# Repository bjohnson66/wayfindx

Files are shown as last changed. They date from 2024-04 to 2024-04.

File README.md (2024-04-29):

# WayFindX

WayFindX is a handheld GPS receiver project developed by Bradley Johnson and Abele Atresso. The project aims to create a portable navigation device that enhances outdoor navigation capabilities for users such as hikers, adventurers, and outdoor enthusiasts. WayFindX provides essential features including position and velocity tracking, storage of multiple locations, and distance calculation to selected stored positions.

# Youtube Promo

IWayFindX Promo Video (https://www.youtube.com/watch?v=03FtzsMHSRk)

## Key Features

- Display of user position and velocity information
- Storage of multiple locations for navigation
- Calculation of distance to selected stored positions
- Intuitive user interface with control buttons and LCD display

## Hardware Components

The project utilizes the following hardware components:

- Arduino microcontroller (ATMega328p)
- HD44780 Controlled 20x4 LCD for display
- Four buttons for user input
- NEO-6M GPS module for positioning
- Power Switch and 9V battery for power management
- Additional components for connectivity
- Custom-designed 3D printed case for enclosure

## Software Interface

WayFindX provides a user-friendly interface with control buttons for navigation and interaction. The software is designed to display essential information such as current position, stored locations, and operational modes on the LCD display. Users can cycle through saved positions, select operations, and execute actions with ease.

## Challenges Faced

The project encountered various challenges including serial communication, interfacing with new ICs, soldering, and enclosure design. Overcoming these challenges required careful planning, experimentation, and troubleshooting.

For detailed documentation and code implementation, refer to the project source code and comments.

See /docs for relevant hardware, software, and misc documentation.

[Doxygen HTML Documentation](https://raw.githubusercontent.com/bjohnson66/wayfindx/main/docs/Doxygen/html/index.html)

[Doxygen PDF Documentatoin](https://github.com/bjohnson66/wayfindx/blob/88b1bcc49ac1252769d0535202fbb5b85fcedd5b/docs/Doxygen/doxygen_latex_pdf_out.pdf)

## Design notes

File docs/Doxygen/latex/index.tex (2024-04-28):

\chapter{Way\+FindX}
\hypertarget{index}{}\label{index}\index{WayFindX@{WayFindX}}
Synopsis of the Way\+FindX Embedded Systems Project.

Synopsis of the Way\+FindX Embedded Systems Project.   

Way\+FindX is a handheld GPS receiver project developed by Avengers Assembly, consisting of Bradley Johnson and Abele Atresso. The project aims to create a portable navigation device that enhances outdoor navigation capabilities for users such as hikers, adventurers, and outdoor enthusiasts. Way\+FindX provides essential features including position and velocity tracking, storage of multiple locations, and distance calculation to selected stored positions.\hypertarget{index_features}{}\doxysection{\texorpdfstring{Key Features}{Key Features}}\label{index_features}

\begin{DoxyItemize}
\item Display of user position and velocity information
\item Storage of multiple locations for navigation
\item Calculation of distance to selected stored positions
\item Intuitive user interface with control buttons and LCD display
\end{DoxyItemize}\hypertarget{index_hardware}{}\doxysection{\texorpdfstring{Hardware Components}{Hardware Components}}\label{index_hardware}
The project utilizes the following hardware components\+:
\begin{DoxyItemize}
\item Arduino microcontroller (ATMega328p)
\item HD44780 Controlled 20x4 LCD for display
\item Control Stick for user input
\item NEO-\/6M GPS module for positioning
\item Power Switch and 9V battery for power management
\item Additional components for connectivity
\item Custom-\/designed 3D printed case for enclosure
\end{DoxyItemize}\hypertarget{index_software}{}\doxysection{\texorpdfstring{Software Interface}{Software Interface}}\label{index_software}
Way\+FindX provides a user-\/friendly interface with control buttons for navigation and interaction. The software is designed to display essential information such as current position, stored locations, and operational modes on the LCD display. Users can cycle through saved positions, select operations, and execute actions with ease.\hypertarget{index_challenges}{}\doxysection{\texorpdfstring{Challenges Faced}{Challenges Faced}}\label{index_challenges}
The project encountered various challenges including serial communication, interfacing with new ICs, soldering, and enclosure design. Overcoming these challenges required careful planning, experimentation, and troubleshooting.

For detailed documentation and code implementation, refer to the project source code and comments.\textbackslash{} \begin{DoxyVersion}{Version}
1.\+0 
\end{DoxyVersion}
\begin{DoxyCopyright}{Copyright}
(C) 2024 Bradley Johnson and Abele Atresso 
\end{DoxyCopyright}

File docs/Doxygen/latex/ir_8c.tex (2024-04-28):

\doxysection{G\+:/\+Project\+\_\+\+Files/\+Way\+Find\+X/wfx\+\_\+sw/wfx\+\_\+sw/ir/ir.c File Reference}
\hypertarget{ir_8c}{}\label{ir_8c}\index{G:/Project\_Files/WayFindX/wfx\_sw/wfx\_sw/ir/ir.c@{G:/Project\_Files/WayFindX/wfx\_sw/wfx\_sw/ir/ir.c}}
{\ttfamily \#include "{}ir.\+h"{}}\newline
{\ttfamily \#include $<$avr/interrupt.\+h$>$}\newline
{\ttfamily \#include "{}../ut/utilities.\+h"{}}\newline
\doxysubsubsection*{Functions}
\begin{DoxyCompactItemize}
\item 
\mbox{\hyperlink{ir_8c_add2d7cdddfb682dcc0391e60cf42c7d6}{ISR}} (TIMER0\+\_\+\+OVF\+\_\+vect)
\item 
\mbox{\hyperlink{ir_8c_a7cfcbe42bd266750aeb6e5d71e5ea479}{ISR}} (TIMER2\+\_\+\+OVF\+\_\+vect)
\item 
void \mbox{\hyperlink{ir_8c_a398213820d1862c262f45bb51a4bb934}{ir\+\_\+init}} ()
\begin{DoxyCompactList}\small\item\em Initializes interrupt system functionality. \end{DoxyCompactList}\end{DoxyCompactItemize}
\doxysubsubsection*{Variables}
\begin{DoxyCompactItemize}
\item 
\mbox{\hyperlink{ut__types_8h_a1f1825b69244eb3ad2c7165ddc99c956}{uint16\+\_\+t}} \mbox{\hyperlink{ir_8c_a420cef67ebc0cf3d472f957806f1b8b4}{ir\+\_\+sec\+\_\+counter}} = 0
\item 
\mbox{\hyperlink{ut__types_8h_a5338510a6d3a27844de9a766a4303d46}{boolean\+\_\+t}} \mbox{\hyperlink{ir_8c_a3869ada31829485498d4bdbf1d4cc6e9}{ir\+\_\+trigger\+\_\+1hz\+\_\+flag\+\_\+g}} = \mbox{\hyperlink{ut__types_8h_a65e9886d74aaee76545e83dd09011727}{false}}
\end{DoxyCompactItemize}

\doxysubsection{Function Documentation}
\Hypertarget{ir_8c_a398213820d1862c262f45bb51a4bb934}\label{ir_8c_a398213820d1862c262f45bb51a4bb934} 
\index{ir.c@{ir.c}!ir\_init@{ir\_init}}
\index{ir\_init@{ir\_init}!ir.c@{ir.c}}
\doxysubsubsection{\texorpdfstring{ir\_init()}{ir\_init()}}
{\footnotesize\ttfamily void ir\+\_\+init (\begin{DoxyParamCaption}{ }\end{DoxyParamCaption})}

Initializes interrupt system functionality. 

This function configures Timer2 for time management and Timer 0 for background button polling. 

Definition at line \mbox{\hyperlink{ir_8c_source_l00038}{38}} of file \mbox{\hyperlink{ir_8c_source}{ir.\+c}}.

\Hypertarget{ir_8c_add2d7cdddfb682dcc0391e60cf42c7d6}\label{ir_8c_add2d7cdddfb682dcc0391e60cf42c7d6} 
\index{ir.c@{ir.c}!ISR@{ISR}}
\index{ISR@{ISR}!ir.c@{ir.c}}
\doxysubsubsection{\texorpdfstring{ISR()}{ISR()}\hspace{0.1cm}{\footnotesize\ttfamily [1/2]}}
{\footnotesize\ttfamily ISR (\begin{DoxyParamCaption}\item[{TIMER0\+\_\+\+OVF\+\_\+vect}]{ }\end{DoxyParamCaption})}

Definition at line \mbox{\hyperlink{ir_8c_source_l00016}{16}} of file \mbox{\hyperlink{ir_8c_source}{ir.\+c}}.

\Hypertarget{ir_8c_a7cfcbe42bd266750aeb6e5d71e5ea479}\label{ir_8c_a7cfcbe42bd266750aeb6e5d71e5ea479} 
\index{ir.c@{ir.c}!ISR@{ISR}}
\index{ISR@{ISR}!ir.c@{ir.c}}
\doxysubsubsection{\texorpdfstring{ISR()}{ISR()}\hspace{0.1cm}{\footnotesize\ttfamily [2/2]}}
{\footnotesize\ttfamily ISR (\begin{DoxyParamCaption}\item[{TIMER2\+\_\+\+OVF\+\_\+vect}]{ }\end{DoxyParamCaption})}

Definition at line \mbox{\hyperlink{ir_8c_source_l00022}{22}} of file \mbox{\hyperlink{ir_8c_source}{ir.\+c}}.

\doxysubsection{Variable Documentation}
\Hypertarget{ir_8c_a420cef67ebc0cf3d472f957806f1b8b4}\label{ir_8c_a420cef67ebc0cf3d472f957806f1b8b4} 
\index{ir.c@{ir.c}!ir\_sec\_counter@{ir\_sec\_counter}}
\index{ir\_sec\_counter@{ir\_sec\_counter}!ir.c@{ir.c}}
\doxysubsubsection{\texorpdfstring{ir\_sec\_counter}{ir\_sec\_counter}}
{\footnotesize\ttfamily \mbox{\hyperlink{ut__types_8h_a1f1825b69244eb3ad2c7165ddc99c956}{uint16\+\_\+t}} ir\+\_\+sec\+\_\+counter = 0}

Seconds counter for indicating TTFF 

Definition at line \mbox{\hyperlink{ir_8c_source_l00006}{6}} of file \mbox{\hyperlink{ir_8c_source}{ir.\+c}}.

\Hypertarget{ir_8c_a3869ada31829485498d4bdbf1d4cc6e9}\label{ir_8c_a3869ada31829485498d4bdbf1d4cc6e9} 
\index{ir.c@{ir.c}!ir\_trigger\_1hz\_flag\_g@{ir\_trigger\_1hz\_flag\_g}}
\index{ir\_trigger\_1hz\_flag\_g@{ir\_trigger\_1hz\_flag\_g}!ir.c@{ir.c}}
\doxysubsubsection{\texorpdfstring{ir\_trigger\_1hz\_flag\_g}{ir\_trigger\_1hz\_flag\_g}}
{\footnotesize\ttfamily \mbox{\hyperlink{ut__types_8h_a5338510a6d3a27844de9a766a4303d46}{boolean\+\_\+t}} ir\+\_\+trigger\+\_\+1hz\+\_\+flag\+\_\+g = \mbox{\hyperlink{ut__types_8h_a65e9886d74aaee76545e83dd09011727}{false}}}

Global flag indicating 1Hz trigger 

Definition at line \mbox{\hyperlink{ir_8c_source_l00007}{7}} of file \mbox{\hyperlink{ir_8c_source}{ir.\+c}}.

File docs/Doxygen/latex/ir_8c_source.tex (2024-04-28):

\doxysection{ir.\+c}
\hypertarget{ir_8c_source}{}\label{ir_8c_source}\index{G:/Project\_Files/WayFindX/wfx\_sw/wfx\_sw/ir/ir.c@{G:/Project\_Files/WayFindX/wfx\_sw/wfx\_sw/ir/ir.c}}
\mbox{\hyperlink{ir_8c}{Go to the documentation of this file.}}
\begin{DoxyCode}{0}
\DoxyCodeLine{\Hypertarget{ir_8c_source_l00001}00001\ \textcolor{preprocessor}{\#include\ "{}\mbox{\hyperlink{ir_8h}{ir.h}}"{}}}
\DoxyCodeLine{\Hypertarget{ir_8c_source_l00002}00002\ \textcolor{preprocessor}{\#include\ <avr/interrupt.h>}}
\DoxyCodeLine{\Hypertarget{ir_8c_source_l00003}00003\ \textcolor{preprocessor}{\#include\ "{}\mbox{\hyperlink{utilities_8h}{../ut/utilities.h}}"{}}}
\DoxyCodeLine{\Hypertarget{ir_8c_source_l00004}00004\ }
\DoxyCodeLine{\Hypertarget{ir_8c_source_l00005}00005\ \textcolor{comment}{//global}}
\DoxyCodeLine{\Hypertarget{ir_8c_source_l00006}\mbox{\hyperlink{ir_8c_a420cef67ebc0cf3d472f957806f1b8b4}{00006}}\ \mbox{\hyperlink{ut__types_8h_a1f1825b69244eb3ad2c7165ddc99c956}{uint16\_t}}\ \mbox{\hyperlink{ir_8c_a420cef67ebc0cf3d472f957806f1b8b4}{ir\_sec\_counter}}\ =\ 0;\ }
\DoxyCodeLine{\Hypertarget{ir_8c_source_l00007}\mbox{\hyperlink{ir_8c_a3869ada31829485498d4bdbf1d4cc6e9}{00007}}\ \mbox{\hyperlink{ut__types_8h_a5338510a6d3a27844de9a766a4303d46}{boolean\_t}}\ \mbox{\hyperlink{ir_8c_a3869ada31829485498d4bdbf1d4cc6e9}{ir\_trigger\_1hz\_flag\_g}}\ =\ \textcolor{keyword}{false};\ }
\DoxyCodeLine{\Hypertarget{ir_8c_source_l00011}00011\ \textcolor{comment}{//local\ static}}
\DoxyCodeLine{\Hypertarget{ir_8c_source_l00012}00012\ \textcolor{keyword}{static}\ \mbox{\hyperlink{ut__types_8h_aba7bc1797add20fe3efdf37ced1182c5}{uint8\_t}}\ timer2\_overflow\_counter;}
\DoxyCodeLine{\Hypertarget{ir_8c_source_l00013}00013\ }
\DoxyCodeLine{\Hypertarget{ir_8c_source_l00014}00014\ }
\DoxyCodeLine{\Hypertarget{ir_8c_source_l00015}00015\ \textcolor{comment}{//\ Interrupt\ Service\ Routine\ for\ Timer0\ overflow:\ Poll\ all\ four\ buttons\ in\ background\ set\ state\ if\ we\ have\ polled\ enough\ times}}
\DoxyCodeLine{\Hypertarget{ir_8c_source_l00016}\mbox{\hyperlink{ir_8c_add2d7cdddfb682dcc0391e60cf42c7d6}{00016}}\ \mbox{\hyperlink{ir_8c_add2d7cdddfb682dcc0391e60cf42c7d6}{ISR}}(TIMER0\_OVF\_vect)\ \{}
\DoxyCodeLine{\Hypertarget{ir_8c_source_l00017}00017\ \ \ \ \ \mbox{\hyperlink{utilities_8c_a88ffabf71aed5f9ff12e47960d74ad3a}{ut\_poll\_btns}}();}
\DoxyCodeLine{\Hypertarget{ir_8c_source_l00018}00018\ \ \ \ \ TCNT0\ =\ 0;}
\DoxyCodeLine{\Hypertarget{ir_8c_source_l00019}00019\ \}}
\DoxyCodeLine{\Hypertarget{ir_8c_source_l00020}00020\ }
\DoxyCodeLine{\Hypertarget{ir_8c_source_l00021}00021\ \textcolor{comment}{//\ Interrupt\ Service\ Routine\ for\ Timer2\ overflow:\ Used\ to\ trip\ trigger\ flag\ at\ 1Hz}}
\DoxyCodeLine{\Hypertarget{ir_8c_source_l00022}\mbox{\hyperlink{ir_8c_a7cfcbe42bd266750aeb6e5d71e5ea479}{00022}}\ \mbox{\hyperlink{ir_8c_add2d7cdddfb682dcc0391e60cf42c7d6}{ISR}}(TIMER2\_OVF\_vect)\ \{}
\DoxyCodeLine{\Hypertarget{ir_8c_source_l00023}00023\ \ \ \ \ timer2\_overflow\_counter++;}
\DoxyCodeLine{\Hypertarget{ir_8c_source_l00024}00024\ \ \ \ \ \textcolor{keywordflow}{if}\ (timer2\_overflow\_counter\ >=\ 15)\{}
\DoxyCodeLine{\Hypertarget{ir_8c_source_l00025}00025\ \ \ \ \ \ \ \ \ timer2\_overflow\_counter\ =\ 0;}
\DoxyCodeLine{\Hypertarget{ir_8c_source_l00026}00026\ \ \ \ \ \ \ \ \ \mbox{\hyperlink{ir_8c_a420cef67ebc0cf3d472f957806f1b8b4}{ir\_sec\_counter}}++;}
\DoxyCodeLine{\Hypertarget{ir_8c_source_l00027}00027\ \ \ \ \ \ \ \ \ \textcolor{keywordflow}{if}\ (!\mbox{\hyperlink{ir_8c_a3869ada31829485498d4bdbf1d4cc6e9}{ir\_trigger\_1hz\_flag\_g}})\{}
\DoxyCodeLine{\Hypertarget{ir_8c_source_l00028}00028\ \ \ \ \ \ \ \ \ \ \ \ \ \mbox{\hyperlink{ir_8c_a3869ada31829485498d4bdbf1d4cc6e9}{ir\_trigger\_1hz\_flag\_g}}\ =\ \textcolor{keyword}{true};}
\DoxyCodeLine{\Hypertarget{ir_8c_source_l00029}00029\ \ \ \ \ \ \ \ \ \}}
\DoxyCodeLine{\Hypertarget{ir_8c_source_l00030}00030\ \ \ \ \ \}}
\DoxyCodeLine{\Hypertarget{ir_8c_source_l00031}00031\ \}}
\DoxyCodeLine{\Hypertarget{ir_8c_source_l00032}00032\ }
\DoxyCodeLine{\Hypertarget{ir_8c_source_l00038}\mbox{\hyperlink{ir_8c_a398213820d1862c262f45bb51a4bb934}{00038}}\ \textcolor{keywordtype}{void}\ \mbox{\hyperlink{ir_8c_a398213820d1862c262f45bb51a4bb934}{ir\_init}}()}
\DoxyCodeLine{\Hypertarget{ir_8c_source_l00039}00039\ \{}
\DoxyCodeLine{\Hypertarget{ir_8c_source_l00040}00040\ \ \ \ \ cli();}
\DoxyCodeLine{\Hypertarget{ir_8c_source_l00041}00041\ \ \ \ \ \textcolor{comment}{//-\/-\/-\/-\/-\/-\/-\/-\/-\/-\/-\/-\/-\/-\/-\/-\/-\/-\/-\/-\/-\/-\/-\/-\/-\/-\/-\/-\/-\/-\/-\/-\/-\/-\/-\/-\/-\/-\/-\/-\/-\/-\/-\/-\/-\/-\/}}
\DoxyCodeLine{\Hypertarget{ir_8c_source_l00042}00042\ \ \ \ \ \textcolor{comment}{//timer\ 0\ for\ background\ button\ polling}}
\DoxyCodeLine{\Hypertarget{ir_8c_source_l00043}00043\ \ \ \ \ OCR0A\ =\ 2;\ \ \ \ \ \ \ \ \textcolor{comment}{//\ Set\ TOP\ (maximum\ value\ for\ counter)}}
\DoxyCodeLine{\Hypertarget{ir_8c_source_l00044}00044\ \ }
\DoxyCodeLine{\Hypertarget{ir_8c_source_l00045}00045\ \ \ \ \ TCNT0\ =\ 0x00;\ \ \ \ \ \ \ \textcolor{comment}{//set\ counter\ to\ zero}}
\DoxyCodeLine{\Hypertarget{ir_8c_source_l00046}00046\ \ \ \ \ TCCR0A\ =\ 0x00;\ \ \ \ \ \ \textcolor{comment}{//set\ TCCR1A\ to\ zero\ before\ configuring\ timer0}}
\DoxyCodeLine{\Hypertarget{ir_8c_source_l00047}00047\ \ \ \ \ TCCR0B\ =\ 0x00;}
\DoxyCodeLine{\Hypertarget{ir_8c_source_l00048}00048\ \ \ \ \ \textcolor{comment}{//\ TOP\ is\ defined\ as\ OCR0A\ when\ WGM2:0\ =\ 5}}
\DoxyCodeLine{\Hypertarget{ir_8c_source_l00049}00049\ }
\DoxyCodeLine{\Hypertarget{ir_8c_source_l00050}00050\ \ \ \ \ \textcolor{comment}{//\ Set\ pre-\/scaler\ to\ /8}}
\DoxyCodeLine{\Hypertarget{ir_8c_source_l00051}00051\ \ \ \ \ TCCR0B\ |=\ (1\ <<\ CS01);}
\DoxyCodeLine{\Hypertarget{ir_8c_source_l00052}00052\ \ \ \ \ \textcolor{comment}{//\ Enable\ Timer0\ Overflow\ Interrupt}}
\DoxyCodeLine{\Hypertarget{ir_8c_source_l00053}00053\ \ \ \ \ TIMSK0\ |=\ (1\ <<\ TOIE0);}
\DoxyCodeLine{\Hypertarget{ir_8c_source_l00054}00054\ \ \ \ \ \textcolor{comment}{//\ Initialize\ Timer0\ count}}
\DoxyCodeLine{\Hypertarget{ir_8c_source_l00055}00055\ \ \ \ \ TCNT0\ =\ 0;}
\DoxyCodeLine{\Hypertarget{ir_8c_source_l00056}00056\ }
\DoxyCodeLine{\Hypertarget{ir_8c_source_l00057}00057\ }
\DoxyCodeLine{\Hypertarget{ir_8c_source_l00058}00058\ \ \ \ \ \textcolor{comment}{//Set\ up\ timer2\ for\ 1\ hz\ task\ managment}}
\DoxyCodeLine{\Hypertarget{ir_8c_source_l00059}00059\ \ \ \ \ \textcolor{comment}{//\ Set\ Timer2\ in\ normal\ mode\ (WGM22:0\ =\ 0)}}
\DoxyCodeLine{\Hypertarget{ir_8c_source_l00060}00060\ \ \ \ \ TCCR2A\ =\ 0x00;}
\DoxyCodeLine{\Hypertarget{ir_8c_source_l00061}00061\ \ \ \ \ TCCR2B\ =\ 0x00;}
\DoxyCodeLine{\Hypertarget{ir_8c_source_l00062}00062\ \ \ \ \ \textcolor{comment}{//\ Set\ pre-\/scaler\ to\ clk/1024\ for\ smoothing}}
\DoxyCodeLine{\Hypertarget{ir_8c_source_l00063}00063\ \ \ \ \ TCCR2B\ |=\ (1\ <<\ CS22)\ |\ (1\ <<\ CS21)\ |\ (1\ <<\ CS20);\ \textcolor{comment}{//\ Pre-\/scaler\ =\ 64}}
\DoxyCodeLine{\Hypertarget{ir_8c_source_l00064}00064\ \ \ \ \ \textcolor{comment}{//\ Enable\ Timer2\ Overflow\ Interrupt}}
\DoxyCodeLine{\Hypertarget{ir_8c_source_l00065}00065\ \ \ \ \ TIMSK2\ |=\ (1\ <<\ TOIE2);}
\DoxyCodeLine{\Hypertarget{ir_8c_source_l00066}00066\ }
\DoxyCodeLine{\Hypertarget{ir_8c_source_l00067}00067\ }
\DoxyCodeLine{\Hypertarget{ir_8c_source_l00068}00068\ \ \ \ \ sei();\ \textcolor{comment}{//\ Enable\ interrupts.}}
\DoxyCodeLine{\Hypertarget{ir_8c_source_l00069}00069\ \}}

\end{DoxyCode}

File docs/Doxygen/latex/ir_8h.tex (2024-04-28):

\doxysection{G\+:/\+Project\+\_\+\+Files/\+Way\+Find\+X/wfx\+\_\+sw/wfx\+\_\+sw/ir/ir.h File Reference}
\hypertarget{ir_8h}{}\label{ir_8h}\index{G:/Project\_Files/WayFindX/wfx\_sw/wfx\_sw/ir/ir.h@{G:/Project\_Files/WayFindX/wfx\_sw/wfx\_sw/ir/ir.h}}

Header file containing common functions and definitions for the interrupt system \textquotesingle{}computer software component"{} or CSC.  

{\ttfamily \#include "{}../ut/ut\+\_\+types.\+h"{}}\newline
\doxysubsubsection*{Functions}
\begin{DoxyCompactItemize}
\item 
void \mbox{\hyperlink{ir_8h_a398213820d1862c262f45bb51a4bb934}{ir\+\_\+init}} ()
\begin{DoxyCompactList}\small\item\em Initializes interrupt system functionality. \end{DoxyCompactList}\end{DoxyCompactItemize}
\doxysubsubsection*{Variables}
\begin{DoxyCompactItemize}
\item 
\mbox{\hyperlink{ut__types_8h_a5338510a6d3a27844de9a766a4303d46}{boolean\+\_\+t}} \mbox{\hyperlink{ir_8h_a3869ada31829485498d4bdbf1d4cc6e9}{ir\+\_\+trigger\+\_\+1hz\+\_\+flag\+\_\+g}}
\item 
\mbox{\hyperlink{ut__types_8h_a1f1825b69244eb3ad2c7165ddc99c956}{uint16\+\_\+t}} \mbox{\hyperlink{ir_8h_a420cef67ebc0cf3d472f957806f1b8b4}{ir\+\_\+sec\+\_\+counter}}
\end{DoxyCompactItemize}

\doxysubsection{Detailed Description}
Header file containing common functions and definitions for the interrupt system \textquotesingle{}computer software component"{} or CSC. 

This file provides declarations for common utility functions and definitions associated with the interrupt system. \begin{DoxyVersion}{Version}
1.\+0 
\end{DoxyVersion}
\begin{DoxyCopyright}{Copyright}
(C) 2024 Bradley Johnson and Abele Atresso 
\end{DoxyCopyright}

Definition in file \mbox{\hyperlink{ir_8h_source}{ir.\+h}}.

\doxysubsection{Function Documentation}
\Hypertarget{ir_8h_a398213820d1862c262f45bb51a4bb934}\label{ir_8h_a398213820d1862c262f45bb51a4bb934} 
\index{ir.h@{ir.h}!ir\_init@{ir\_init}}
\index{ir\_init@{ir\_init}!ir.h@{ir.h}}
\doxysubsubsection{\texorpdfstring{ir\_init()}{ir\_init()}}
{\footnotesize\ttfamily void ir\+\_\+init (\begin{DoxyParamCaption}{ }\end{DoxyParamCaption})}

Initializes interrupt system functionality. 

This function configures Timer2 for time management and Timer 0 for background button polling. 

Definition at line \mbox{\hyperlink{ir_8c_source_l00038}{38}} of file \mbox{\hyperlink{ir_8c_source}{ir.\+c}}.

\doxysubsection{Variable Documentation}
\Hypertarget{ir_8h_a420cef67ebc0cf3d472f957806f1b8b4}\label{ir_8h_a420cef67ebc0cf3d472f957806f1b8b4} 
\index{ir.h@{ir.h}!ir\_sec\_counter@{ir\_sec\_counter}}
\index{ir\_sec\_counter@{ir\_sec\_counter}!ir.h@{ir.h}}
\doxysubsubsection{\texorpdfstring{ir\_sec\_counter}{ir\_sec\_counter}}
{\footnotesize\ttfamily \mbox{\hyperlink{ut__types_8h_a1f1825b69244eb3ad2c7165ddc99c956}{uint16\+\_\+t}} ir\+\_\+sec\+\_\+counter\hspace{0.3cm}{\ttfamily [extern]}}

Seconds counter for indicating TTFF 

Definition at line \mbox{\hyperlink{ir_8c_source_l00006}{6}} of file \mbox{\hyperlink{ir_8c_source}{ir.\+c}}.

\Hypertarget{ir_8h_a3869ada31829485498d4bdbf1d4cc6e9}\label{ir_8h_a3869ada31829485498d4bdbf1d4cc6e9} 
\index{ir.h@{ir.h}!ir\_trigger\_1hz\_flag\_g@{ir\_trigger\_1hz\_flag\_g}}
\index{ir\_trigger\_1hz\_flag\_g@{ir\_trigger\_1hz\_flag\_g}!ir.h@{ir.h}}
\doxysubsubsection{\texorpdfstring{ir\_trigger\_1hz\_flag\_g}{ir\_trigger\_1hz\_flag\_g}}
{\footnotesize\ttfamily \mbox{\hyperlink{ut__types_8h_a5338510a6d3a27844de9a766a4303d46}{boolean\+\_\+t}} ir\+\_\+trigger\+\_\+1hz\+\_\+flag\+\_\+g\hspace{0.3cm}{\ttfamily [extern]}}

Global flag indicating 1Hz trigger 

Definition at line \mbox{\hyperlink{ir_8c_source_l00007}{7}} of file \mbox{\hyperlink{ir_8c_source}{ir.\+c}}.

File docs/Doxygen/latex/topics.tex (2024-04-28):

\doxysection{Topics}
Here is a list of all topics with brief descriptions\+:\begin{DoxyCompactList}
\item \contentsline{section}{LCD library \texorpdfstring{$<$}{<}lcd.\+h\texorpdfstring{$>$}{>}}{\pageref{group__pfleury__lcd}}{}
\item \contentsline{section}{UART Library \texorpdfstring{$<$}{<}uart.\+h\texorpdfstring{$>$}{>}}{\pageref{group__pfleury__uart}}{}
\end{DoxyCompactList}

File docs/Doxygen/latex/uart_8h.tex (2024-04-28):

\doxysection{G\+:/\+Project\+\_\+\+Files/\+Way\+Find\+X/wfx\+\_\+sw/wfx\+\_\+sw/lib/uart.h File Reference}
\hypertarget{uart_8h}{}\label{uart_8h}\index{G:/Project\_Files/WayFindX/wfx\_sw/wfx\_sw/lib/uart.h@{G:/Project\_Files/WayFindX/wfx\_sw/wfx\_sw/lib/uart.h}}
{\ttfamily \#include $<$avr/pgmspace.\+h$>$}\newline
\doxysubsubsection*{Macros}
\begin{DoxyCompactItemize}
\item 
\#define \mbox{\hyperlink{group__pfleury__uart_ga367ff7b5de225ed936a63239ad4adb0b}{UART\+\_\+\+BAUD\+\_\+\+SELECT}}(baud\+Rate,  xtal\+Cpu)~(((xtal\+Cpu) + 8UL \texorpdfstring{$\ast$}{*} (baud\+Rate)) / (16UL \texorpdfstring{$\ast$}{*} (baud\+Rate)) -\/1UL)
\begin{DoxyCompactList}\small\item\em UART Baudrate Expression. \end{DoxyCompactList}\item 
\#define \mbox{\hyperlink{group__pfleury__uart_ga1a02d45130520cb651ab313e69039382}{UART\+\_\+\+BAUD\+\_\+\+SELECT\+\_\+\+DOUBLE\+\_\+\+SPEED}}(baud\+Rate,  xtal\+Cpu)~( ((((xtal\+Cpu) + 4UL \texorpdfstring{$\ast$}{*} (baud\+Rate)) / (8UL \texorpdfstring{$\ast$}{*} (baud\+Rate)) -\/1UL)) \texorpdfstring{$\vert$}{|} 0x8000)
\begin{DoxyCompactList}\small\item\em UART Baudrate Expression for ATmega double speed mode. \end{DoxyCompactList}\item 
\#define \mbox{\hyperlink{group__pfleury__uart_ga5bdd6772c246436bb14377095de79b31}{UART\+\_\+\+RX\+\_\+\+BUFFER\+\_\+\+SIZE}}~32
\begin{DoxyCompactList}\small\item\em Size of the circular receive buffer, must be power of 2. \end{DoxyCompactList}\item 
\#define \mbox{\hyperlink{group__pfleury__uart_ga05f5d709605c6317c97e4974bec3402a}{UART\+\_\+\+TX\+\_\+\+BUFFER\+\_\+\+SIZE}}~32
\begin{DoxyCompactList}\small\item\em Size of the circular transmit buffer, must be power of 2. \end{DoxyCompactList}\item 
\#define \mbox{\hyperlink{group__pfleury__uart_gabcdb1041d763560cd8f8e722370dfd37}{UART\+\_\+\+FRAME\+\_\+\+ERROR}}~0x1000
\begin{DoxyCompactList}\small\item\em Framing Error by UART ~\newline
 \end{DoxyCompactList}\item 
\#define \mbox{\hyperlink{group__pfleury__uart_ga3183177e3613d8785d8cc8516931beb6}{UART\+\_\+\+OVERRUN\+\_\+\+ERROR}}~0x0800
\begin{DoxyCompactList}\small\item\em Overrun condition by UART ~\newline
 \end{DoxyCompactList}\item 
\#define \mbox{\hyperlink{group__pfleury__uart_ga946e3d317937e003d2057bf19e96dd1d}{UART\+\_\+\+PARITY\+\_\+\+ERROR}}~0x0400
\begin{DoxyCompactList}\small\item\em Parity Error by UART ~\newline
 \end{DoxyCompactList}\item 
\#define \mbox{\hyperlink{group__pfleury__uart_ga94758f3dad6864703b7417d3e40f11df}{UART\+\_\+\+BUFFER\+\_\+\+OVERFLOW}}~0x0200
\begin{DoxyCompactList}\small\item\em receive ringbuffer overflow \end{DoxyCompactList}\item 
\#define \mbox{\hyperlink{group__pfleury__uart_ga77ba544d423ff42d400220a05303f268}{UART\+\_\+\+NO\+\_\+\+DATA}}~0x0100
\begin{DoxyCompactList}\small\item\em no receive data available ~\newline
 \end{DoxyCompactList}\item 
\#define \mbox{\hyperlink{group__pfleury__uart_gae9e143569df2285379bc55f9f5595bf9}{uart\+\_\+puts\+\_\+P}}(\+\_\+\+\_\+s)~\mbox{\hyperlink{group__pfleury__uart_ga6d78b6744db6232f52b4616402036c2f}{uart\+\_\+puts\+\_\+p}}(PSTR(\+\_\+\+\_\+s))
\begin{DoxyCompactList}\small\item\em Macro to automatically put a string constant into program memory. \end{DoxyCompactList}\item 
\#define \mbox{\hyperlink{group__pfleury__uart_gaabd7a5b0c15611ee9ecb2873cc9ee87a}{uart1\+\_\+puts\+\_\+P}}(\+\_\+\+\_\+s)~\mbox{\hyperlink{group__pfleury__uart_ga1e8074d0a2d5922601c5db2f9777ba79}{uart1\+\_\+puts\+\_\+p}}(PSTR(\+\_\+\+\_\+s))
\begin{DoxyCompactList}\small\item\em Macro to automatically put a string constant into program memory. \end{DoxyCompactList}\end{DoxyCompactItemize}
\doxysubsubsection*{Functions}
\begin{DoxyCompactItemize}
\item 
void \mbox{\hyperlink{group__pfleury__uart_gac19a76bb7d446125734a67f9f4b68991}{uart\+\_\+init}} (unsigned int baudrate)
\begin{DoxyCompactList}\small\item\em Initialize UART and set baudrate. \end{DoxyCompactList}\item 
unsigned int \mbox{\hyperlink{group__pfleury__uart_gaefaab30a8338ec46a6be35b99b1b4f09}{uart\+\_\+getc}} (void)
\begin{DoxyCompactList}\small\item\em Get received byte from ringbuffer. \end{DoxyCompactList}\item 
void \mbox{\hyperlink{group__pfleury__uart_gad975221bc08b901e4c7ad69f9c9a97e2}{uart\+\_\+putc}} (unsigned char data)
\begin{DoxyCompactList}\small\item\em Put byte to ringbuffer for transmitting via UART. \end{DoxyCompactList}\item 
void \mbox{\hyperlink{group__pfleury__uart_gae52facc0a56086a365bb0018160d8d71}{uart\+\_\+puts}} (const char \texorpdfstring{$\ast$}{*}s)
\begin{DoxyCompactList}\small\item\em Put string to ringbuffer for transmitting via UART. \end{DoxyCompactList}\item 
void \mbox{\hyperlink{group__pfleury__uart_ga6d78b6744db6232f52b4616402036c2f}{uart\+\_\+puts\+\_\+p}} (const char \texorpdfstring{$\ast$}{*}s)
\begin{DoxyCompactList}\small\item\em Put string from program memory to ringbuffer for transmitting via UART. \end{DoxyCompactList}\item 
void \mbox{\hyperlink{group__pfleury__uart_ga4db697cb5469fd70e794fa7df73a6d6a}{uart1\+\_\+init}} (unsigned int baudrate)
\begin{DoxyCompactList}\small\item\em Initialize USART1 (only available on selected ATmegas) \end{DoxyCompactList}\item 
unsigned int \mbox{\hyperlink{group__pfleury__uart_gaeb1405c641e5bc9b7224018f5e8d90de}{uart1\+\_\+getc}} (void)
\begin{DoxyCompactList}\small\item\em Get received byte of USART1 from ringbuffer. (only available on selected ATmega) \end{DoxyCompactList}\item 
void \mbox{\hyperlink{group__pfleury__uart_gab465f689d197fadfbacc374fc9411154}{uart1\+\_\+putc}} (unsigned char data)
\begin{DoxyCompactList}\small\item\em Put byte to ringbuffer for transmitting via USART1 (only available on selected ATmega) \end{DoxyCompactList}\item 
void \mbox{\hyperlink{group__pfleury__uart_ga5568f8f3913b218fd4d0346af78831b2}{uart1\+\_\+puts}} (const char \texorpdfstring{$\ast$}{*}s)
\begin{DoxyCompactList}\small\item\em Put string to ringbuffer for transmitting via USART1 (only available on selected ATmega) \end{DoxyCompactList}\item 
void \mbox{\hyperlink{group__pfleury__uart_ga1e8074d0a2d5922601c5db2f9777ba79}{uart1\+\_\+puts\+\_\+p}} (const char \texorpdfstring{$\ast$}{*}s)
\begin{DoxyCompactList}\small\item\em Put string from program memory to ringbuffer for transmitting via USART1 (only available on selected ATmega) \end{DoxyCompactList}\end{DoxyCompactItemize}

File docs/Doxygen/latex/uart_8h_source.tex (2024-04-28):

\doxysection{uart.\+h}
\hypertarget{uart_8h_source}{}\label{uart_8h_source}\index{G:/Project\_Files/WayFindX/wfx\_sw/wfx\_sw/lib/uart.h@{G:/Project\_Files/WayFindX/wfx\_sw/wfx\_sw/lib/uart.h}}
\mbox{\hyperlink{uart_8h}{Go to the documentation of this file.}}
\begin{DoxyCode}{0}
\DoxyCodeLine{\Hypertarget{uart_8h_source_l00001}00001\ \textcolor{preprocessor}{\#ifndef\ UART\_H}}
\DoxyCodeLine{\Hypertarget{uart_8h_source_l00002}00002\ \textcolor{preprocessor}{\#define\ UART\_H}}
\DoxyCodeLine{\Hypertarget{uart_8h_source_l00003}00003\ \textcolor{comment}{/************************************************************************}}
\DoxyCodeLine{\Hypertarget{uart_8h_source_l00004}00004\ \textcolor{comment}{Title:\ \ \ \ Interrupt\ UART\ library\ with\ receive/transmit\ circular\ buffers}}
\DoxyCodeLine{\Hypertarget{uart_8h_source_l00005}00005\ \textcolor{comment}{Author:\ \ \ Peter\ Fleury\ <pfleury@gmx.ch>\ \ http://tinyurl.com/peterfleury}}
\DoxyCodeLine{\Hypertarget{uart_8h_source_l00006}00006\ \textcolor{comment}{File:\ \ \ \ \ \$Id:\ uart.h,v\ 1.13\ 2015/01/11\ 13:53:25\ peter\ Exp\ \$}}
\DoxyCodeLine{\Hypertarget{uart_8h_source_l00007}00007\ \textcolor{comment}{Software:\ AVR-\/GCC\ 4.x,\ AVR\ Libc\ 1.4\ or\ higher}}
\DoxyCodeLine{\Hypertarget{uart_8h_source_l00008}00008\ \textcolor{comment}{Hardware:\ any\ AVR\ with\ built-\/in\ UART/USART}}
\DoxyCodeLine{\Hypertarget{uart_8h_source_l00009}00009\ \textcolor{comment}{Usage:\ \ \ \ see\ Doxygen\ manual}}
\DoxyCodeLine{\Hypertarget{uart_8h_source_l00010}00010\ \textcolor{comment}{}}
\DoxyCodeLine{\Hypertarget{uart_8h_source_l00011}00011\ \textcolor{comment}{LICENSE:}}
\DoxyCodeLine{\Hypertarget{uart_8h_source_l00012}00012\ \textcolor{comment}{\ \ \ \ Copyright\ (C)\ 2015\ Peter\ Fleury,\ GNU\ General\ Public\ License\ Version\ 3}}
\DoxyCodeLine{\Hypertarget{uart_8h_source_l00013}00013\ \textcolor{comment}{}}
\DoxyCodeLine{\Hypertarget{uart_8h_source_l00014}00014\ \textcolor{comment}{\ \ \ \ This\ program\ is\ free\ software;\ you\ can\ redistribute\ it\ and/or\ modify}}
\DoxyCodeLine{\Hypertarget{uart_8h_source_l00015}00015\ \textcolor{comment}{\ \ \ \ it\ under\ the\ terms\ of\ the\ GNU\ General\ Public\ License\ as\ published\ by}}
\DoxyCodeLine{\Hypertarget{uart_8h_source_l00016}00016\ \textcolor{comment}{\ \ \ \ the\ Free\ Software\ Foundation;\ either\ version\ 3\ of\ the\ License,\ or}}
\DoxyCodeLine{\Hypertarget{uart_8h_source_l00017}00017\ \textcolor{comment}{\ \ \ \ any\ later\ version.}}
\DoxyCodeLine{\Hypertarget{uart_8h_source_l00018}00018\ \textcolor{comment}{}}
\DoxyCodeLine{\Hypertarget{uart_8h_source_l00019}00019\ \textcolor{comment}{\ \ \ \ This\ program\ is\ distributed\ in\ the\ hope\ that\ it\ will\ be\ useful,}}
\DoxyCodeLine{\Hypertarget{uart_8h_source_l00020}00020\ \textcolor{comment}{\ \ \ \ but\ WITHOUT\ ANY\ WARRANTY;\ without\ even\ the\ implied\ warranty\ of}}
\DoxyCodeLine{\Hypertarget{uart_8h_source_l00021}00021\ \textcolor{comment}{\ \ \ \ MERCHANTABILITY\ or\ FITNESS\ FOR\ A\ PARTICULAR\ PURPOSE.\ \ See\ the}}
\DoxyCodeLine{\Hypertarget{uart_8h_source_l00022}00022\ \textcolor{comment}{\ \ \ \ GNU\ General\ Public\ License\ for\ more\ details.}}
\DoxyCodeLine{\Hypertarget{uart_8h_source_l00023}00023\ \textcolor{comment}{}}
\DoxyCodeLine{\Hypertarget{uart_8h_source_l00024}00024\ \textcolor{comment}{************************************************************************/}}
\DoxyCodeLine{\Hypertarget{uart_8h_source_l00025}00025\ }
\DoxyCodeLine{\Hypertarget{uart_8h_source_l00050}00050\ \textcolor{preprocessor}{\#include\ <avr/pgmspace.h>}}
\DoxyCodeLine{\Hypertarget{uart_8h_source_l00051}00051\ }
\DoxyCodeLine{\Hypertarget{uart_8h_source_l00052}00052\ \textcolor{preprocessor}{\#if\ (\_\_GNUC\_\_\ *\ 100\ +\ \_\_GNUC\_MINOR\_\_)\ <\ 405}}
\DoxyCodeLine{\Hypertarget{uart_8h_source_l00053}00053\ \textcolor{preprocessor}{\#error\ "{}This\ library\ requires\ AVR-\/GCC\ 4.5\ or\ later,\ update\ to\ newer\ AVR-\/GCC\ compiler\ !"{}}}
\DoxyCodeLine{\Hypertarget{uart_8h_source_l00054}00054\ \textcolor{preprocessor}{\#endif}}
\DoxyCodeLine{\Hypertarget{uart_8h_source_l00055}00055\ }
\DoxyCodeLine{\Hypertarget{uart_8h_source_l00056}00056\ }
\DoxyCodeLine{\Hypertarget{uart_8h_source_l00060}00060\ \textcolor{comment}{/*}}
\DoxyCodeLine{\Hypertarget{uart_8h_source_l00061}00061\ \textcolor{comment}{**\ constants\ and\ macros}}
\DoxyCodeLine{\Hypertarget{uart_8h_source_l00062}00062\ \textcolor{comment}{*/}}
\DoxyCodeLine{\Hypertarget{uart_8h_source_l00063}00063\ }
\DoxyCodeLine{\Hypertarget{uart_8h_source_l00064}00064\ }
\DoxyCodeLine{\Hypertarget{uart_8h_source_l00069}\mbox{\hyperlink{group__pfleury__uart_ga367ff7b5de225ed936a63239ad4adb0b}{00069}}\ \textcolor{preprocessor}{\#define\ UART\_BAUD\_SELECT(baudRate,xtalCpu)\ \ (((xtalCpu)\ +\ 8UL\ *\ (baudRate))\ /\ (16UL\ *\ (baudRate))\ -\/1UL)}}
\DoxyCodeLine{\Hypertarget{uart_8h_source_l00070}00070\ }
\DoxyCodeLine{\Hypertarget{uart_8h_source_l00075}\mbox{\hyperlink{group__pfleury__uart_ga1a02d45130520cb651ab313e69039382}{00075}}\ \textcolor{preprocessor}{\#define\ UART\_BAUD\_SELECT\_DOUBLE\_SPEED(baudRate,xtalCpu)\ (\ ((((xtalCpu)\ +\ 4UL\ *\ (baudRate))\ /\ (8UL\ *\ (baudRate))\ -\/1UL))\ |\ 0x8000)}}
\DoxyCodeLine{\Hypertarget{uart_8h_source_l00076}00076\ }
\DoxyCodeLine{\Hypertarget{uart_8h_source_l00082}00082\ \textcolor{preprocessor}{\#ifndef\ UART\_RX\_BUFFER\_SIZE}}
\DoxyCodeLine{\Hypertarget{uart_8h_source_l00083}\mbox{\hyperlink{group__pfleury__uart_ga5bdd6772c246436bb14377095de79b31}{00083}}\ \textcolor{preprocessor}{\#define\ UART\_RX\_BUFFER\_SIZE\ 32}}
\DoxyCodeLine{\Hypertarget{uart_8h_source_l00084}00084\ \textcolor{preprocessor}{\#endif}}
\DoxyCodeLine{\Hypertarget{uart_8h_source_l00085}00085\ }
\DoxyCodeLine{\Hypertarget{uart_8h_source_l00091}00091\ \textcolor{preprocessor}{\#ifndef\ UART\_TX\_BUFFER\_SIZE}}
\DoxyCodeLine{\Hypertarget{uart_8h_source_l00092}\mbox{\hyperlink{group__pfleury__uart_ga05f5d709605c6317c97e4974bec3402a}{00092}}\ \textcolor{preprocessor}{\#define\ UART\_TX\_BUFFER\_SIZE\ 32}}
\DoxyCodeLine{\Hypertarget{uart_8h_source_l00093}00093\ \textcolor{preprocessor}{\#endif}}
\DoxyCodeLine{\Hypertarget{uart_8h_source_l00094}00094\ }
\DoxyCodeLine{\Hypertarget{uart_8h_source_l00095}00095\ \textcolor{comment}{/*\ test\ if\ the\ size\ of\ the\ circular\ buffers\ fits\ into\ SRAM\ */}}
\DoxyCodeLine{\Hypertarget{uart_8h_source_l00096}00096\ \textcolor{preprocessor}{\#if\ (\ (UART\_RX\_BUFFER\_SIZE+UART\_TX\_BUFFER\_SIZE)\ >=\ (RAMEND-\/0x60\ )\ )}}
\DoxyCodeLine{\Hypertarget{uart_8h_source_l00097}00097\ \textcolor{preprocessor}{\#error\ "{}size\ of\ UART\_RX\_BUFFER\_SIZE\ +\ UART\_TX\_BUFFER\_SIZE\ larger\ than\ size\ of\ SRAM"{}}}
\DoxyCodeLine{\Hypertarget{uart_8h_source_l00098}00098\ \textcolor{preprocessor}{\#endif}}
\DoxyCodeLine{\Hypertarget{uart_8h_source_l00099}00099\ }
\DoxyCodeLine{\Hypertarget{uart_8h_source_l00100}00100\ \textcolor{comment}{/*}}
\DoxyCodeLine{\Hypertarget{uart_8h_source_l00101}00101\ \textcolor{comment}{**\ high\ byte\ error\ return\ code\ of\ uart\_getc()}}
\DoxyCodeLine{\Hypertarget{uart_8h_source_l00102}00102\ \textcolor{comment}{*/}}
\DoxyCodeLine{\Hypertarget{uart_8h_source_l00103}\mbox{\hyperlink{group__pfleury__uart_gabcdb1041d763560cd8f8e722370dfd37}{00103}}\ \textcolor{preprocessor}{\#define\ UART\_FRAME\_ERROR\ \ \ \ \ \ 0x1000\ \ \ \ \ \ \ \ \ \ \ \ \ \ }}
\DoxyCodeLine{\Hypertarget{uart_8h_source_l00104}\mbox{\hyperlink{group__pfleury__uart_ga3183177e3613d8785d8cc8516931beb6}{00104}}\ \textcolor{preprocessor}{\#define\ UART\_OVERRUN\_ERROR\ \ \ \ 0x0800\ \ \ \ \ \ \ \ \ \ \ \ \ \ }}
\DoxyCodeLine{\Hypertarget{uart_8h_source_l00105}\mbox{\hyperlink{group__pfleury__uart_ga946e3d317937e003d2057bf19e96dd1d}{00105}}\ \textcolor{preprocessor}{\#define\ UART\_PARITY\_ERROR\ \ \ \ \ 0x0400\ \ \ \ \ \ \ \ \ \ \ \ \ \ }}
\DoxyCodeLine{\Hypertarget{uart_8h_source_l00106}\mbox{\hyperlink{group__pfleury__uart_ga94758f3dad6864703b7417d3e40f11df}{00106}}\ \textcolor{preprocessor}{\#define\ UART\_BUFFER\_OVERFLOW\ \ 0x0200\ \ \ \ \ \ \ \ \ \ \ \ \ \ }}
\DoxyCodeLine{\Hypertarget{uart_8h_source_l00107}\mbox{\hyperlink{group__pfleury__uart_ga77ba544d423ff42d400220a05303f268}{00107}}\ \textcolor{preprocessor}{\#define\ UART\_NO\_DATA\ \ \ \ \ \ \ \ \ \ 0x0100\ \ \ \ \ \ \ \ \ \ \ \ \ \ }}
\DoxyCodeLine{\Hypertarget{uart_8h_source_l00110}00110\ \textcolor{comment}{/*}}
\DoxyCodeLine{\Hypertarget{uart_8h_source_l00111}00111\ \textcolor{comment}{**\ function\ prototypes}}
\DoxyCodeLine{\Hypertarget{uart_8h_source_l00112}00112\ \textcolor{comment}{*/}}
\DoxyCodeLine{\Hypertarget{uart_8h_source_l00113}00113\ }
\DoxyCodeLine{\Hypertarget{uart_8h_source_l00119}\mbox{\hyperlink{group__pfleury__uart_gac19a76bb7d446125734a67f9f4b68991}{00119}}\ \textcolor{keyword}{extern}\ \textcolor{keywordtype}{void}\ \mbox{\hyperlink{group__pfleury__uart_gac19a76bb7d446125734a67f9f4b68991}{uart\_init}}(\textcolor{keywordtype}{unsigned}\ \textcolor{keywordtype}{int}\ baudrate);}
\DoxyCodeLine{\Hypertarget{uart_8h_source_l00120}00120\ }
\DoxyCodeLine{\Hypertarget{uart_8h_source_l00121}00121\ }
\DoxyCodeLine{\Hypertarget{uart_8h_source_l00146}\mbox{\hyperlink{group__pfleury__uart_gaefaab30a8338ec46a6be35b99b1b4f09}{00146}}\ \textcolor{keyword}{extern}\ \textcolor{keywordtype}{unsigned}\ \textcolor{keywordtype}{int}\ \mbox{\hyperlink{group__pfleury__uart_gaefaab30a8338ec46a6be35b99b1b4f09}{uart\_getc}}(\textcolor{keywordtype}{void});}
\DoxyCodeLine{\Hypertarget{uart_8h_source_l00147}00147\ }
\DoxyCodeLine{\Hypertarget{uart_8h_source_l00148}00148\ }
\DoxyCodeLine{\Hypertarget{uart_8h_source_l00154}\mbox{\hyperlink{group__pfleury__uart_gad975221bc08b901e4c7ad69f9c9a97e2}{00154}}\ \textcolor{keyword}{extern}\ \textcolor{keywordtype}{void}\ \mbox{\hyperlink{group__pfleury__uart_gad975221bc08b901e4c7ad69f9c9a97e2}{uart\_putc}}(\textcolor{keywordtype}{unsigned}\ \textcolor{keywordtype}{char}\ data);}
\DoxyCodeLine{\Hypertarget{uart_8h_source_l00155}00155\ }
\DoxyCodeLine{\Hypertarget{uart_8h_source_l00156}00156\ }
\DoxyCodeLine{\Hypertarget{uart_8h_source_l00167}\mbox{\hyperlink{group__pfleury__uart_gae52facc0a56086a365bb0018160d8d71}{00167}}\ \textcolor{keyword}{extern}\ \textcolor{keywordtype}{void}\ \mbox{\hyperlink{group__pfleury__uart_gae52facc0a56086a365bb0018160d8d71}{uart\_puts}}(\textcolor{keyword}{const}\ \textcolor{keywordtype}{char}\ *s\ );}
\DoxyCodeLine{\Hypertarget{uart_8h_source_l00168}00168\ }
\DoxyCodeLine{\Hypertarget{uart_8h_source_l00169}00169\ }
\DoxyCodeLine{\Hypertarget{uart_8h_source_l00181}\mbox{\hyperlink{group__pfleury__uart_ga6d78b6744db6232f52b4616402036c2f}{00181}}\ \textcolor{keyword}{extern}\ \textcolor{keywordtype}{void}\ \mbox{\hyperlink{group__pfleury__uart_ga6d78b6744db6232f52b4616402036c2f}{uart\_puts\_p}}(\textcolor{keyword}{const}\ \textcolor{keywordtype}{char}\ *s\ );}
\DoxyCodeLine{\Hypertarget{uart_8h_source_l00182}00182\ }
\DoxyCodeLine{\Hypertarget{uart_8h_source_l00186}\mbox{\hyperlink{group__pfleury__uart_gae9e143569df2285379bc55f9f5595bf9}{00186}}\ \textcolor{preprocessor}{\#define\ uart\_puts\_P(\_\_s)\ \ \ \ \ \ \ uart\_puts\_p(PSTR(\_\_s))}}
\DoxyCodeLine{\Hypertarget{uart_8h_source_l00187}00187\ }
\DoxyCodeLine{\Hypertarget{uart_8h_source_l00188}00188\ }
\DoxyCodeLine{\Hypertarget{uart_8h_source_l00189}00189\ }
\DoxyCodeLine{\Hypertarget{uart_8h_source_l00191}\mbox{\hyperlink{group__pfleury__uart_ga4db697cb5469fd70e794fa7df73a6d6a}{00191}}\ \textcolor{keyword}{extern}\ \textcolor{keywordtype}{void}\ \mbox{\hyperlink{group__pfleury__uart_ga4db697cb5469fd70e794fa7df73a6d6a}{uart1\_init}}(\textcolor{keywordtype}{unsigned}\ \textcolor{keywordtype}{int}\ baudrate);}
\DoxyCodeLine{\Hypertarget{uart_8h_source_l00193}\mbox{\hyperlink{group__pfleury__uart_gaeb1405c641e5bc9b7224018f5e8d90de}{00193}}\ \textcolor{keyword}{extern}\ \textcolor{keywordtype}{unsigned}\ \textcolor{keywordtype}{int}\ \mbox{\hyperlink{group__pfleury__uart_gaeb1405c641e5bc9b7224018f5e8d90de}{uart1\_getc}}(\textcolor{keywordtype}{void});}
\DoxyCodeLine{\Hypertarget{uart_8h_source_l00195}\mbox{\hyperlink{group__pfleury__uart_gab465f689d197fadfbacc374fc9411154}{00195}}\ \textcolor{keyword}{extern}\ \textcolor{keywordtype}{void}\ \mbox{\hyperlink{group__pfleury__uart_gab465f689d197fadfbacc374fc9411154}{uart1\_putc}}(\textcolor{keywordtype}{unsigned}\ \textcolor{keywordtype}{char}\ data);}
\DoxyCodeLine{\Hypertarget{uart_8h_source_l00197}\mbox{\hyperlink{group__pfleury__uart_ga5568f8f3913b218fd4d0346af78831b2}{00197}}\ \textcolor{keyword}{extern}\ \textcolor{keywordtype}{void}\ \mbox{\hyperlink{group__pfleury__uart_ga5568f8f3913b218fd4d0346af78831b2}{uart1\_puts}}(\textcolor{keyword}{const}\ \textcolor{keywordtype}{char}\ *s\ );}
\DoxyCodeLine{\Hypertarget{uart_8h_source_l00199}\mbox{\hyperlink{group__pfleury__uart_ga1e8074d0a2d5922601c5db2f9777ba79}{00199}}\ \textcolor{keyword}{extern}\ \textcolor{keywordtype}{void}\ \mbox{\hyperlink{group__pfleury__uart_ga1e8074d0a2d5922601c5db2f9777ba79}{uart1\_puts\_p}}(\textcolor{keyword}{const}\ \textcolor{keywordtype}{char}\ *s\ );}
\DoxyCodeLine{\Hypertarget{uart_8h_source_l00201}\mbox{\hyperlink{group__pfleury__uart_gaabd7a5b0c15611ee9ecb2873cc9ee87a}{00201}}\ \textcolor{preprocessor}{\#define\ uart1\_puts\_P(\_\_s)\ \ \ \ \ \ \ uart1\_puts\_p(PSTR(\_\_s))}}
\DoxyCodeLine{\Hypertarget{uart_8h_source_l00202}00202\ }
\DoxyCodeLine{\Hypertarget{uart_8h_source_l00206}00206\ \textcolor{preprocessor}{\#endif\ }\textcolor{comment}{//\ UART\_H}}
\DoxyCodeLine{\Hypertarget{uart_8h_source_l00207}00207\ }

\end{DoxyCode}

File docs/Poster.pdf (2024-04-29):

# WayFindX – Handheld GPS Navigation Device

# Team Members: Bradley Johnson, Abele Atresso

## Abstract

WayFindX is a handheld GPS receiver project developed by Bradley Johnson and Abele Atresso. The project aims to create a portable navigation device that enhances outdoor navigation capabilities for users such as hikers, adventurers, and outdoor enthusiasts. WayFindX provides essential features including position and velocity tracking, storage of multiple locations, and distance calculation to selected stored positions.

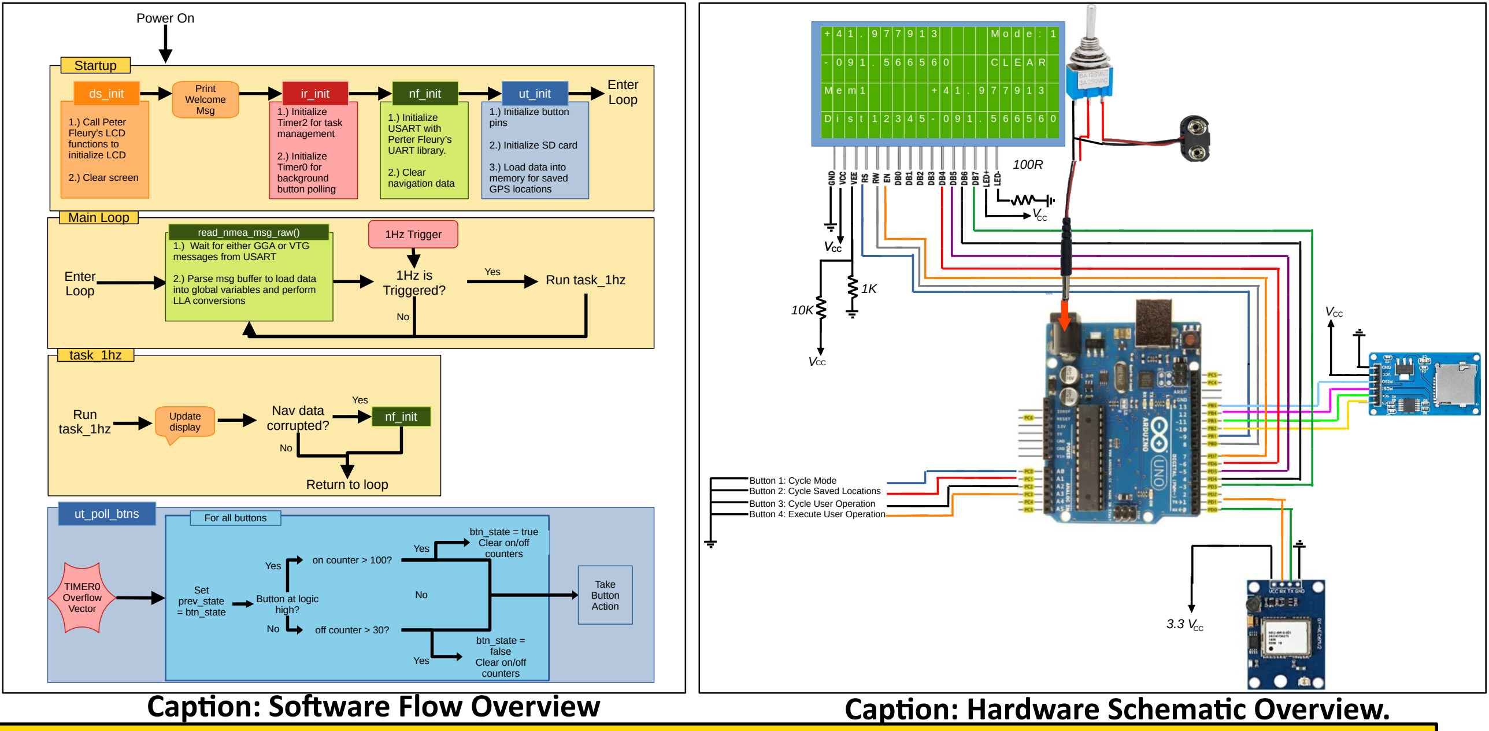
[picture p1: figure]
VCC; Button 1: Cycle Mode Button 2: Cycle Saved Locations Button 3: Cycle User Operation Button 4: Execute User Operation; 3.3 VCC; Caption: Software Flow Overview; Caption: Hardware Schematic Overview.; Yes; Power On; Main Loop; Enter Loop; 1Hz is Triggered?; Run task_1hz; Startup; Print Welcome Msg; 1.) Call Peter Fleury’s LCD functions to initialize LCD; 2.) Clear screen; ds_init; 1.) Initialize Timer2 for task management; 2.) Initialize Timer0 for background button polling; ir_init; 1.) Initialize USART with Perter Fleury’s UART library.; 2.) Clear navigation data; nf_init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
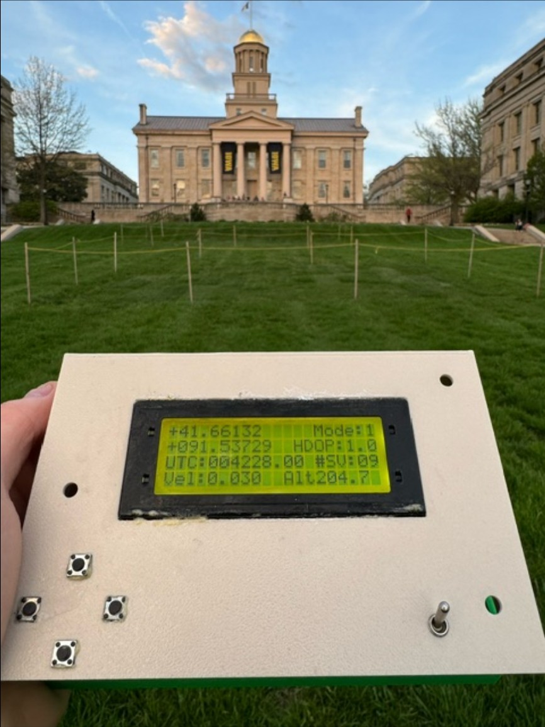
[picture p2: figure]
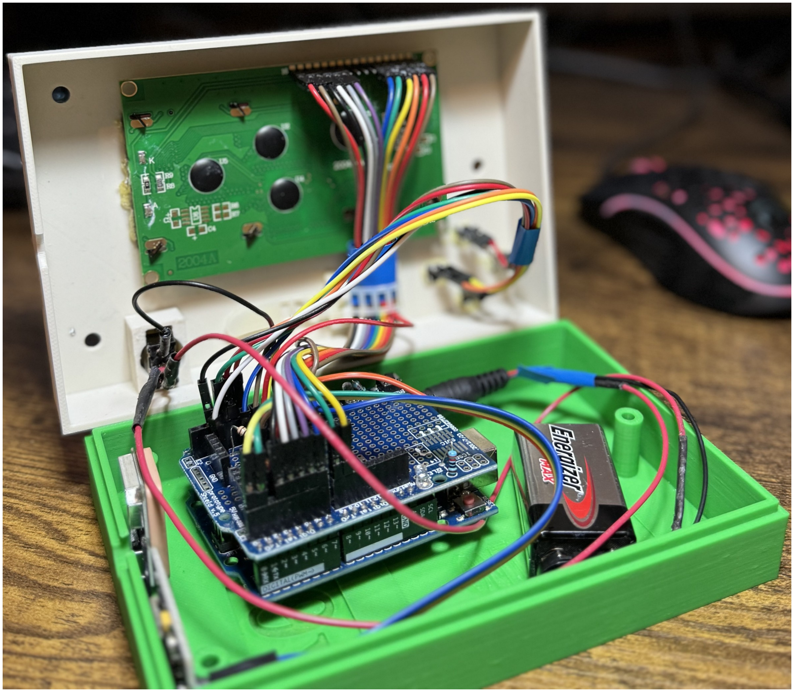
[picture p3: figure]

ECE:3360 Embedded Systems 2024 | The University of Iowa

## System Description

## Introduction

## Results

## Lessons Learned

Key Features:
- Display of user position and velocity information
- Storage of multiple locations for navigation
- Calculation of distance to selected stored positions
- Intuitive user interface with control buttons and LCD display
- Reduced clock-speed of 4MHz increases battery life The project utilizes the following hardware components:
- Arduino microcontroller (ATMega328p)
- HD44780 Controlled 20x4 LCD for display
- Four buttons for user input
- NEO-6M GPS module for positioning
- Power Switch and 9V battery for power management
- SD Card and SD Card Adapter Module for non-volatile storage

Development began with a detailed preliminary design; making sure that the project would be feasible within the time frame and minimizing problems before they become an issue. Then we developed on a prototype breadboard for rapid software development while the box was being 3D printed. During hardware assembly care was taken to ensure a clean and well-managed inside as users would need to access it in order to change the battery and it makes it easier to trouble shoot when wires/soldering are carefully and thoughtfully managed.

The WayFindX proves to be a useful and fun-to-use handheld GPS device. In testing, the WayFindX has a position error that matches that of an iPhone and an error in its distance calculation of only about 2 meters in small distances. (This is due to floating point errors introduced by the limitations of the 16-bit ATMega328P).

The WayFindX proved to be a successful prototype device that in its current state would be a fun device to have on hikes, camping trips, or exploring. We already have ideas for how to improve it: rechargeable battery, seamless switching between wall-powered/battery powered, adjustable contrast, LED on/off switch for day time power conservation.

Caption: WayFindX at the base of the Old Capitol; showing distance to Seamans Center

Caption: Exposed WayFindX device.

●UART can be thrown off by shaking and electric noise; this can be fixed in software by detecting it and re-initializing UART.
●DONT TRY TO GLUE 4 BUTTONS AT ONCE WITH ONLY TWO HANDS! Instead, glue them one at a time.
●Doing string to floating point conversions manually can be thwarted by floating point arithmetic errors. Just use standard libraries for that.
●When designing a 3D print, ensure meticulous consideration for every component, leaving ample space for wires and ensuring all elements fit snugly within the same enclosure for seamless integration and optimal functionality.

Caption: Picture of WayFindX running in STAT Mode (Mode 0)

The WayFindX was inspired by the group’s desire to create a useful product with practical applications. It allows for easy distance estimation out in open areas or over long distances where other measuring tools are not feasible. It also could be used to lay a “trail of breadcrumbs.” The user has 10 way points which they can leave behind to find their way back.

The WayFindX also allows users to answer the age-old question: “I wonder how far it is from here to ___?” Additionally, the STAT mode gives users the capability to nerd out about the GPS GNSS Constellation; letting them monitor their HDOP, the number of Svs used in their PVT solution, their ground speed, their altitude, and UTC time in seconds.

## Conclusion

## References

Special thank you to:
●Peter Fluery for the use of his LCD and UART libraries
●RJH from University of Texas at Dallas for his guide on interfacing with an SD card via SPI

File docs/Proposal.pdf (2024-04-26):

# Embedded Systems Project Proposal

## Avengers Assembly: Bradley Johnson and Abele Atresso

## Overview:

The Avengers Assembly project aims to develop a handheld GPS receiver capable of displaying essential user position and velocity information, storing multiple locations, and calculating the distance to selected stored positions. This device will enhance navigation capabilities for outdoor enthusiasts, hikers, and adventurers.

## Parts:

1. Arduino – ATMega328p microcontroller
2. HD44780 Controlled 20x4 LCD for display
3. Control Stick for user input (included in lab kit)
4. NEO-6M GPS module for positioning
5. Power Switch and 9V battery for power management
6. Additional components such as buttons and headers for connectivity
7. Custom-designed 3D printed case for enclosure and protection

## Hardware:

The LCD will be wired in the same way as it was for Lab 4 and Lab 5. The microcontroller that drives the LCD is the same, so the only changes will be via software. The NEO-6M module will have its VCC connected to 5V, its GND to the common GND of the Arduino, its Ax pin to the Rx Arduino pin, and its Tx pin to the Tx Arduino pin. Further study of the NEO-6M datasheet revealed that additional resistors are not needed for the serial data lines of the NEO-6M, though it should be connected to the 3.3V power supply instead of the 5V lone. Figure 1 (Next page) shows the proposed Arduino pinout configuration. The 4 control buttons will use both hardware and software debounce and use pins PD5, PD4, PD3, and PD2.

## Figure 1

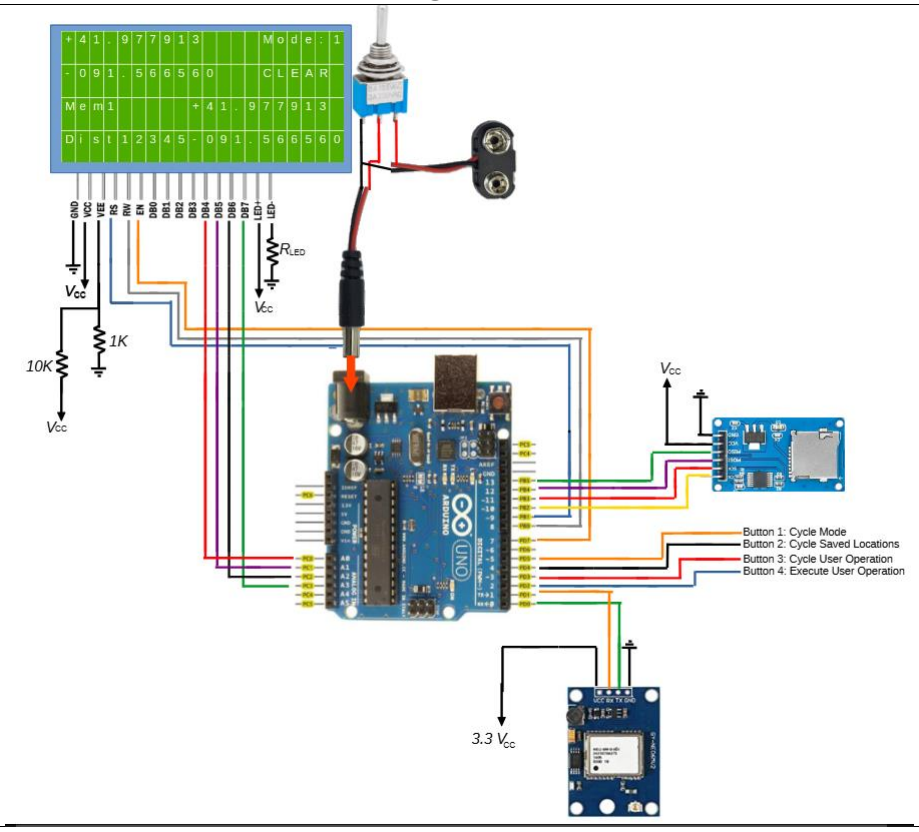
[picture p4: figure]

## Box:

The box for the final product will be 3D printed similarly to the preliminary design shown in Figure 2. Ideally, the box will be built such that the batteries can be easily changed. The 4 squares are sized to hold 4 buttons. The big rectangle will house the 20x4 LCD display flush with the face of the box. The smaller rectangle will house the power switch. The three circles around the edge of the box are for screws to secure the two halves together (though the box does have enough tension to snap together).

## Figure 2

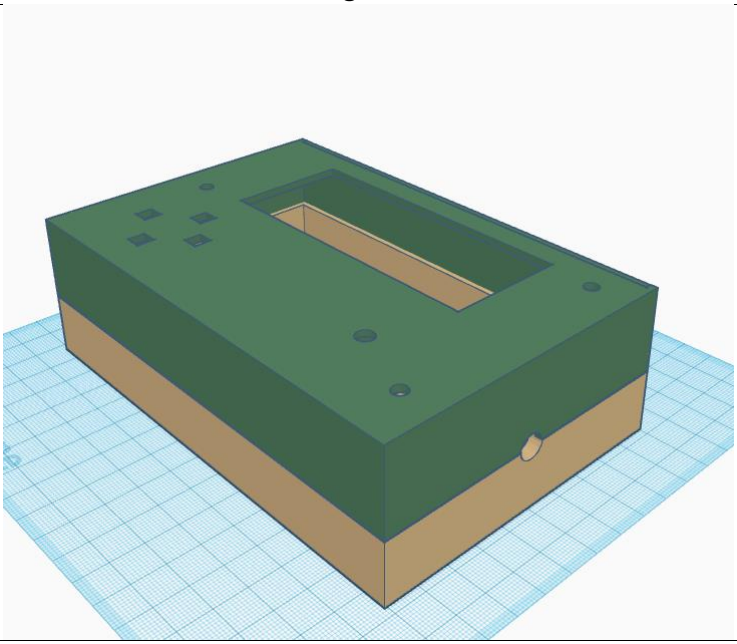
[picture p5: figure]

## Figure 3

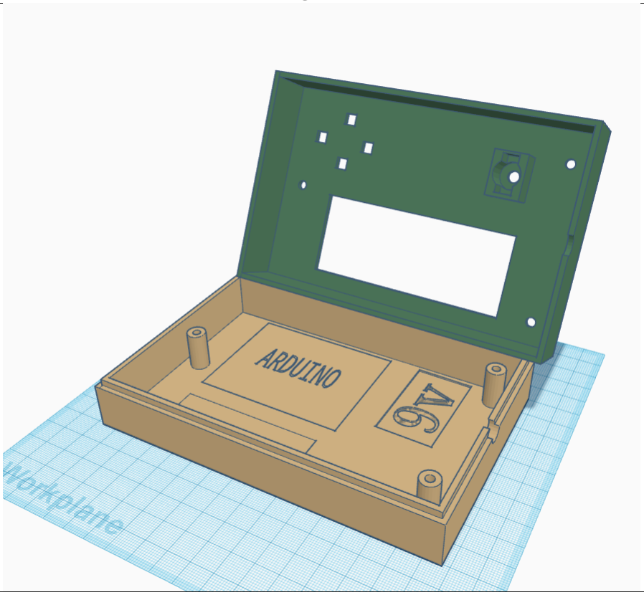
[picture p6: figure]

## Software and User Interface:

The user will interface with the device using 4 buttons. Button 1 will cycle between Mode 1 and Mode 2. The other 3 buttons will only have functionality while in Mode 1. There will be a power switch to turn the device on and off.

## In Mode 1:

In Mode 1, Button 2 will cycle through saved positions, Button 3 will cycle through user operations, and Button 4 will execute the selected user operation on the selected saved position. The LCD display will show the user’s current Lat/Long position to 6 decimals of precision, one of the stored Lat/Long locations to 6 decimals of precision, the memory index of the stored location, the selected user operation, the current mode, and the distance from the user’s position to the selected stored location.
When the user presses down on the stick, the device will run the selected operation on the selected memory location.
SAVE: Will overwrite the selected memory location with the user’s current position. CLEAR: Will clear the selected memory location
RESET: Will clear all memory locations

## In Mode 2:

The screen will show the current GPS time (GPST) Week Number and second of week SOW, the number of satellite vehicles (SVs) being currently tracked by the receiver module, and the current position. Pushing any button except for Button 1 will have no effect while in Mode 2.

## Figure 4

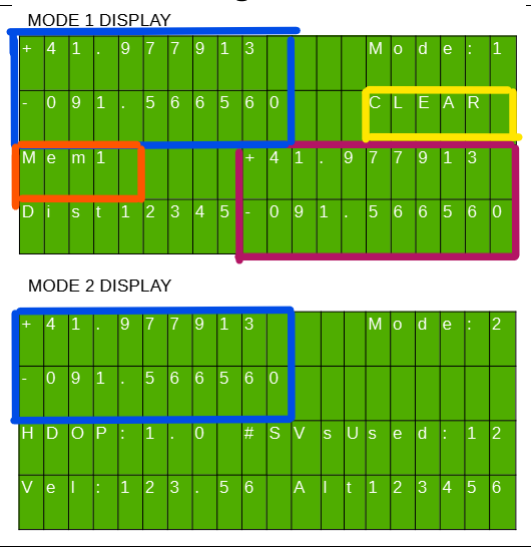
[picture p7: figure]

Figure 3 shows a potential layout of the desired data on the 20x4 LCD in Mode 1 and Mode
2. The current mode is shown in the top right. In both modes, the user’s position is shown in the area highlighted by the blue box in the figure. In Mode 1, the current selected operation is shown in the area highlighted by the yellow box in the figure, the memory index of the selected stored location is shown in the are highlighted by the red box in the figure, and the current stored location is shown in the bottom right (highlighted by the purple box on the figure. In Mode 1, the distance between the user’s position and the selected stored location is shown in the bottom right. This calculation will not consider earth curvature or altitude. It will assume a common altitude (It will assume the user’s altitude in meters is common to the stored location for simpler math).

## Receiving GPS Data

The NEO-6M GPS module provides NMEA data via UART serial output on its Tx and Rx pins and provides GSV, RMC, GSA, GGA, GLL, VTG, TXT message types. We will use the GSA message to find the user’s position, number of SVs used in the PVT solution, the horizontal dilution of precision (HDOP), and altitude in meters. We will use the VTG message to get the user’s ground speed in Km/hr. The display will update at approximately 1Hz.

## Challenges:

Using serial, interfacing with a new IC, soldering parts together, designing/printing box.

## Relevant Datasheets:

ATmega328P:
https://ww1.microchip.com/downloads/en/DeviceDoc/Atmel-7810-Automotive-Microcontrollers-ATmega328P_Datasheet.pdf (https://ww1.microchip.com/downloads/en/DeviceDoc/Atmel-7810-Automotive-Microcontrollers-ATmega328P_Datasheet.pdf)
HD44780:
https://www.sparkfun.com/datasheets/LCD/HD44780.pdf
NEO-6:
https://content.u-blox.com/sites/default/files/products/documents/NEO-6_DataSheet_%28GPS.G6-HW-09005%29.pdf (https://content.u-blox.com/sites/default/files/products/documents/NEO-6_DataSheet_%28GPS.G6-HW-09005%29.pdf)
NMEA:
https://www.sparkfun.com/datasheets/GPS/NMEA%20Reference%20Manual1.pdf

SD Card Reader Breakout Board; https://components101.com/sites/default/files/component_datasheet/Micro-SD-Card-Module-Datasheet.pdf (https://components101.com/sites/default/files/component_datasheet/Micro-SD-Card-Module-Datasheet.pdf)
https://cdn.awsli.com.br/945/945993/arquivos/Datasheet-MicroSD-Module.pdf

SD Card Datasheet:
https://www.convict.lu/pdf/ProdManualSDCardv1.9.pdf

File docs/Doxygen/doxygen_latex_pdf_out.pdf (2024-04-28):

## WayFindX

Version 1.0

Generated by Doxygen 1.10.0

i

1 WayFindX | 1
2 File Index | 3
3 File Documentation | 5

Generated by Doxygen

ii

iii

iv

v

Index | 55

# Chapter 1

# WayFindX

Synopsis of the WayFindX Embedded Systems Project.

Synopsis of the WayFindX Embedded Systems Project.

WayFindX is a handheld GPS receiver project developed by Avengers Assembly, consisting of Bradley Johnson and Abele Atresso. The project aims to create a portable navigation device that enhances outdoor navigation capabilities for users such as hikers, adventurers, and outdoor enthusiasts. WayFindX provides essential features including position and velocity tracking, storage of multiple locations, and distance calculation to selected stored positions.

## 1.1 Key Features

- Display of user position and velocity information
- Storage of multiple locations for navigation
- Calculation of distance to selected stored positions
- Intuitive user interface with control buttons and LCD display

## 1.2 Hardware Components

The project utilizes the following hardware components:

- Arduino microcontroller (ATMega328p)
- HD44780 Controlled 20x4 LCD for display
- Control Stick for user input
- NEO-6M GPS module for positioning
- Power Switch and 9V battery for power management
- Additional components for connectivity
- Custom-designed 3D printed case for enclosure

### 2 WayFindX

## 1.3 Software Interface

WayFindX provides a user-friendly interface with control buttons for navigation and interaction. The software is designed to display essential information such as current position, stored locations, and operational modes on the LCD display. Users can cycle through saved positions, select operations, and execute actions with ease.

## 1.4 Challenges Faced

The project encountered various challenges including serial communication, interfacing with new ICs, soldering, and enclosure design. Overcoming these challenges required careful planning, experimentation, and troubleshooting.

For detailed documentation and code implementation, refer to the project source code and comments.\

Version

1.0

Copyright

(C) 2024 Bradley Johnson and Abele Atresso

# Chapter 2

# File Index

## 2.1 File List

Here is a list of all files with brief descriptions:

G:/Project_Files/WayFindX/wfx_sw/wfx_sw/main.c | | 13
G:/Project_Files/WayFindX/wfx_sw/wfx_sw/ds/ds.c | | | 5
G:/Project_Files/WayFindX/wfx_sw/wfx_sw/ds/ds.h
Header file containing common functions and definitions for the display 'computer software com-
ponent" or CSC | | 6
G:/Project_Files/WayFindX/wfx_sw/wfx_sw/ir/ir.c | | 9
G:/Project_Files/WayFindX/wfx_sw/wfx_sw/ir/ir.h
Header file containing common functions and definitions for the interrupt system 'computer soft-
ware component" or CSC | | 11
G:/Project_Files/WayFindX/wfx_sw/wfx_sw/nf/nf.c | | 17
G:/Project_Files/WayFindX/wfx_sw/wfx_sw/nf/nf.h
Header file containing common functions and definitions for the navigation fetch (NV) CSC | . . | 28
G:/Project_Files/WayFindX/wfx_sw/wfx_sw/nf/nf_types.h | | | 32
G:/Project_Files/WayFindX/wfx_sw/wfx_sw/ut/ut_types.h
Header file containing typedefs for common types | | 38
G:/Project_Files/WayFindX/wfx_sw/wfx_sw/ut/utilities.c | | 40
G:/Project_Files/WayFindX/wfx_sw/wfx_sw/ut/utilities.h
Header file containing common utility functions and definitions | | | 48

### 4 File Index

# Chapter 3

# File Documentation

## 3.1 G:/Project_Files/WayFindX/wfx_sw/wfx_sw/ds/ds.c File Reference

#include "ds.h"

#include "../lib/lcd.h"

#include "../ut/ut_types.h" #include <avr/io.h>

Functions

- void ds_print_string (char ∗inputString, int size, uint8_t row)

Prints a string on the LCD display.
- void ds_init ()

Initializes the LCD display. This function initializes the LCD display and turns on the display.
- void ds_clear ()

Clears the LCD display. This function clears the LCD display.

### 3.1.1 Function Documentation

### 3.1.1.1 ds_clear()

void ds_clear ( )

Clears the LCD display. This function clears the LCD display.

Clears the display.

Definition at line 44 of file ds.c.

### 3.1.1.2 ds_init()

void ds_init ( )

Initializes the LCD display. This function initializes the LCD display and turns on the display.

Uses library to initialize display. If DEBUG is defined, cursor will blink. Otherwise, cursor will be off.

Definition at line 33 of file ds.c.

### 6 File Documentation

### 3.1.1.3 ds_print_string()

void ds_print_string (

char ∗ inputString,

int size,

uint8_t row )

Prints a string on the LCD display.

Parameters

inputString | Pointer to the string to be printed.
size | Size of the string to be printed.
row | indicating what row to place the cursor

Definition at line 14 of file ds.c.

## 3.2 ds.c

Go to the documentation of this file.

00001 #include "ds.h"
00002 #include "../lib/lcd.h" 00003 #include "../ut/ut_types.h" 00004 #include <avr/io.h>
00005
00006
00014 void ds_print_string(char * inputString, int size, uint8_t row)
00015 {
00016 | //Make sure size is legit
00017 | if ((size >= 0) && (size <= MAX_COL) && (row >= 0) && (row < MAX_ROWS))
00018 | {
00019 | lcd_gotoxy((uint8_t)0, row); //send to second line
00020
00021 | for (int i = 0; i < size; i++)
00022 | {
00023 | lcd_putc(inputString[i]); //put i’th char on display
00024 | }
00025 | }
00026 | return;
00027 }
00028
00033 void ds_init()
00034 {
00035 | lcd_init(LCD_DISP_ON);
00036 | lcd_clrscr();
00037 | return;
00038 }
00039
00044 void ds_clear(){
00045 | lcd_clrscr();
00046 }

## 3.3 G:/Project_Files/WayFindX/wfx_sw/wfx_sw/ds/ds.h File Reference

Header file containing common functions and definitions for the display 'computer software component" or CSC.

#include "../ut/ut_types.h"

3.3 G:/Project_Files/WayFindX/wfx_sw/wfx_sw/ds/ds.h File Reference | 7

Macros

- #define MAX_ROWS 4
- #define MAX_COL 20
- #define SPACES " "

Functions

- void ds_print_string (char ∗inputString, int size, uint8_t row)

Prints a string on the LCD display.
- void ds_init ()

Uses library to initialize display. If DEBUG is defined, cursor will blink. Otherwise, cursor will be off.
- void ds_clear ()

Clears the display.

### 3.3.1 Detailed Description

Header file containing common functions and definitions for the display 'computer software component" or CSC.

This file provides declarations for common utility functions and definitions associated with the LCD display.

Version

1.0

Copyright

(C) 2024 Bradley Johnson and Abele Atresso

Definition in file ds.h.

### 3.3.2 Macro Definition Documentation

### 3.3.2.1 MAX_COL

#define MAX_COL 20

Maximum number of columns on the LCD display

Definition at line 14 of file ds.h.

### 3.3.2.2 MAX_ROWS

#define MAX_ROWS 4

Maximum number of rows on the LCD display

Definition at line 13 of file ds.h.

### 8 File Documentation

### 3.3.2.3 SPACES

#define SPACES " "

String of spaces used for clearing the LCD display

Definition at line 15 of file ds.h.

### 3.3.3 Function Documentation

### 3.3.3.1 ds_clear()

void ds_clear ( )

Clears the display.

Clears the display.

Definition at line 44 of file ds.c.

### 3.3.3.2 ds_init()

void ds_init ( )

Uses library to initialize display. If DEBUG is defined, cursor will blink. Otherwise, cursor will be off.

Returns

none

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

Definition at line 33 of file ds.c.

### 3.3.3.3 ds_print_string()

void ds_print_string (

char ∗ inputString,

int size,

uint8_t row )

Prints a string on the LCD display.

Parameters

inputString | Pointer to the string to be printed.
size | Size of the string to be printed.
row | Row index where the cursor will be placed.
inputString | Pointer to the string to be printed.
size | Size of the string to be printed.
row | indicating what row to place the cursor | Generated by Doxygen

3.4 ds.h | 9

Definition at line 14 of file ds.c.

## 3.4 ds.h

Go to the documentation of this file.

00001
00010 #ifndef DS_H_
00011 #define DS_H_
00012
00013 #define MAX_ROWS 4
00014 #define MAX_COL 20
00015 #define SPACES " | "
00018 #include "../ut/ut_types.h"
00019
00027 void ds_print_string(char * inputString, int size, uint8_t row); 00028
00035 void ds_init();
00036
00040 void ds_clear();
00041
00042
00043 #endif /* DS_H_ */

## 3.5 G:/Project_Files/WayFindX/wfx_sw/wfx_sw/ir/ir.c File Reference

#include "ir.h"

#include <avr/interrupt.h> #include "../ut/utilities.h"

Functions

- ISR (TIMER0_OVF_vect)
- ISR (TIMER2_OVF_vect)
- void ir_init ()

Initializes interrupt system functionality.

Variables

- uint16_t ir_sec_counter = 0
- boolean_t ir_trigger_1hz_flag_g = false

### 3.5.1 Function Documentation

### 3.5.1.1 ir_init()

void ir_init ( )

Initializes interrupt system functionality.

This function configures Timer2 for time management and Timer 0 for background button polling.

Definition at line 38 of file ir.c.

### 10 File Documentation

### 3.5.1.2 ISR() [1/2]

ISR (

TIMER0_OVF_vect )

Definition at line 16 of file ir.c.

### 3.5.1.3 ISR() [2/2]

ISR (

TIMER2_OVF_vect )

Definition at line 22 of file ir.c.

### 3.5.2 Variable Documentation

### 3.5.2.1 ir_sec_counter

uint16_t ir_sec_counter = 0

Seconds counter for indicating TTFF

Definition at line 6 of file ir.c.

### 3.5.2.2 ir_trigger_1hz_flag_g

boolean_t ir_trigger_1hz_flag_g = false

Global flag indicating 1Hz trigger

Definition at line 7 of file ir.c.

## 3.6 ir.c

Go to the documentation of this file.

00001 #include "ir.h"
00002 #include <avr/interrupt.h> 00003 #include "../ut/utilities.h" 00004
00005 //global
00006 uint16_t ir_sec_counter = 0;
00007 boolean_t ir_trigger_1hz_flag_g = false; 00011 //local static
00012 static uint8_t timer2_overflow_counter;
00013
00014
00015 // Interrupt Service Routine for Timer0 overflow: Poll all four buttons in background set state if we have polled enough times
00016 ISR(TIMER0_OVF_vect) {
00017 | ut_poll_btns();
00018 | TCNT0 = 0;
00019 }
00020
00021 // Interrupt Service Routine for Timer2 overflow: Used to trip trigger flag at 1Hz 00022 ISR(TIMER2_OVF_vect) {
00023 | timer2_overflow_counter++;
00024 | if (timer2_overflow_counter >= 15){

3.7 G:/Project_Files/WayFindX/wfx_sw/wfx_sw/ir/ir.h File Reference | 11
00025 | timer2_overflow_counter = 0;
00026 | ir_sec_counter++;
00027 | if (!ir_trigger_1hz_flag_g){
00028 | ir_trigger_1hz_flag_g = true;
00029 | }
00030 | }
00031 }
00032
00038 void ir_init()
00039 {
00040 | cli();
00041 | //----------------------------------------------
00042 | //timer 0 for background button polling
00043 | OCR0A = 2; | // Set TOP (maximum value for counter)
00044
00045 | TCNT0 = 0x00; | //set counter to zero
00046 | TCCR0A = 0x00; | //set TCCR1A to zero before configuring timer0
00047 | TCCR0B = 0x00;
00048 | // TOP is defined as OCR0A when WGM2:0 = 5
00049
00050 | // Set pre-scaler to /8
00051 | TCCR0B |= (1 « CS01);
00052 | // Enable Timer0 Overflow Interrupt
00053 | TIMSK0 |= (1 « TOIE0);
00054 | // Initialize Timer0 count
00055 | TCNT0 = 0;
00056
00057
00058 | //Set up timer2 for 1 hz task managment
00059 | // Set Timer2 in normal mode (WGM22:0 = 0)
00060 | TCCR2A = 0x00;
00061 | TCCR2B = 0x00;
00062 | // Set pre-scaler to clk/1024 for smoothing
00063 | TCCR2B |= (1 « CS22) | (1 « CS21) | (1 « CS20); // Pre-scaler = 64
00064 | // Enable Timer2 Overflow Interrupt
00065 | TIMSK2 |= (1 « TOIE2);
00066
00067
00068 | sei(); // Enable interrupts.
00069 }

## 3.7 G:/Project_Files/WayFindX/wfx_sw/wfx_sw/ir/ir.h File Reference

Header file containing common functions and definitions for the interrupt system 'computer software component" or CSC.

#include "../ut/ut_types.h"

Functions

- void ir_init ()

Initializes interrupt system functionality.

Variables

- boolean_t ir_trigger_1hz_flag_g
- uint16_t ir_sec_counter

### 12 File Documentation

### 3.7.1 Detailed Description

Header file containing common functions and definitions for the interrupt system 'computer software component" or CSC.

This file provides declarations for common utility functions and definitions associated with the interrupt system.

Version

1.0

Copyright

(C) 2024 Bradley Johnson and Abele Atresso

Definition in file ir.h.

### 3.7.2 Function Documentation

### 3.7.2.1 ir_init()

void ir_init ( )

Initializes interrupt system functionality.

This function configures Timer2 for time management and Timer 0 for background button polling.

Definition at line 38 of file ir.c.

### 3.7.3 Variable Documentation

### 3.7.3.1 ir_sec_counter

uint16_t ir_sec_counter [extern]

Seconds counter for indicating TTFF

Definition at line 6 of file ir.c.

### 3.7.3.2 ir_trigger_1hz_flag_g

boolean_t ir_trigger_1hz_flag_g [extern]

Global flag indicating 1Hz trigger

Definition at line 7 of file ir.c.

3.8 ir.h | 13

## 3.8 ir.h

Go to the documentation of this file.

00001
00010 #ifndef IR_H_
00011 #define IR_H_
00012
00013 #include "../ut/ut_types.h"
00014
00015 //globals
00016 extern boolean_t ir_trigger_1hz_flag_g; 00017 extern uint16_t ir_sec_counter;
00024 void ir_init();
00025
00026
00027 #endif /* IR_H_ */

## 3.9 G:/Project_Files/WayFindX/wfx_sw/wfx_sw/main.c File Reference

#include <avr/power.h>

#include <avr/io.h>

#include <util/delay.h>

#include "ds/ds.h"

#include "ir/ir.h"

#include "nf/nf.h"

#include "nf/nf_types.h"

#include "ut/utilities.h"

#include "ut/ut_types.h"

#include <string.h>

Macros

- #define F_CPU 4000000UL

Functions

- void startup ()

Performs startup initialization.
- void task_1hz ()

Executes tasks that should occur every 1Hz.
- void update_display ()

Updates the display with relevant information.
- int main (void)

Main loop function.

### 3.9.1 Macro Definition Documentation

### 3.9.1.1 F_CPU

#define F_CPU 4000000UL

Define the CPU frequency to 4MHz.

Definition at line 46 of file main.c.

### 14 File Documentation

### 3.9.2 Function Documentation

### 3.9.2.1 main()

int main (

void )

Main loop function.

This function controls the program flow and will not return. It initializes the peripherals, clears the display, and continuously updates the system behavior.

Definition at line 73 of file main.c.

### 3.9.2.2 startup()

void startup ( )

Performs startup initialization.

< Include display-related functions. < Include interrupt routines. < Include navigation fetch functions < Include utility functions. < Include common type definitions.

This function initializes various peripherals and components during startup, such as the display, interrupt routines, navigation fetch, and utilities. < Initialize display CSC.

< Initialize interrupt routines.

<Initialize navigation fetch CSC.

< Initialize utilities CSC.

Definition at line 93 of file main.c.

### 3.9.2.3 task_1hz()

void task_1hz ( )

Executes tasks that should occur every 1Hz.

This function is called once per second and performs tasks such as updating the display.

Definition at line 130 of file main.c.

### 3.9.2.4 update_display()

void update_display ( )

Updates the display with relevant information.

This function updates the display with information such as GPS coordinates, mode, operation, and memory status.

Definition at line 147 of file main.c.

3.10 main.c | 15

## 3.10 main.c

Go to the documentation of this file.

00001
00045 #ifndef F_CPU
00046 #define F_CPU 4000000UL 00047 #endif
00048
00049 //PORT Pin 2 PD2
00050 #include <avr/power.h> 00051 #include <avr/io.h>
00052 #include <util/delay.h> 00053
00054 #include "ds/ds.h"
00055 #include "ir/ir.h"
00056 #include "nf/nf.h"
00057 #include "nf/nf_types.h" 00058 #include "ut/utilities.h" 00059 #include "ut/ut_types.h" 00060 #include <string.h>
00061
00062 void startup();
00063 void task_1hz();
00064 void update_display(); 00065
00066
00073 int main(void)
00074 {
00075 | startup();
00076 | /* Main loop */
00077 | while (1){
00078 | //read_nmea_msg
00079 | read_nmea_msg_raw();
00080 | if (ir_trigger_1hz_flag_g == true){
00081 | task_1hz();
00082 | ir_trigger_1hz_flag_g = false;
00083 | }
00084 | }
00085 }
00086
00087
00093 void startup(){
00094 | //Initialize
00095 | // Set clock pre-scaler to divide by 4
00096 | clock_prescale_set(clock_div_4);
00097
00098 | // Initialize computer software components (CSC’s)
00099 | ds_init();
00100 | {
00101 | char* welcome = "- - - - ~~~~ - - - -";
00102 | ds_print_string(welcome, MAX_COL, 0);
00103 | }
00104 | { //Welcome Screen - limited scope
00105 | char* welcome = "- - - WayFindX - - -";
00106 | ds_print_string(welcome, MAX_COL, 1);
00107 | }
00108 | {
00109 | char* welcome = "- - - - ~~~~ - - - -";
00110 | ds_print_string(welcome, MAX_COL, 2);
00111 | }
00112 | _delay_ms(0.1f);
00113
00114 | ir_init();
00115 | _delay_ms(0.1f);
00116 | if (nf_init()){
00117 | char* err = " | Nav init failure | ";
00118 | ds_print_string(err, MAX_COL, 1);
00119 | while(1){};
00120 | }
00121 | _delay_ms(0.6f);
00122 | ut_init();
00123 }
00124
00130 void task_1hz(){
00131 | update_display();
00132 | //Condition where USART if out of sync with NEO6-M
00133 | if ((position_fix_indicator[0] == ’1’) && (speed[0] == ’ ’) && (speed[1] == ’ ’)){
00134 | /* Re-Initialize navigation fetch CSC. */
00135 | do {
00136 | char* err = "Nav module off sync!";
00137 | ds_print_string(err, MAX_COL, 1);
00138 | } while(nf_init());
00139 | }
00140 }
00141

### 16 File Documentation

00147 void update_display(){ char line0[MAX_COL] = SPACES; char line1[MAX_COL] = SPACES; char line2[MAX_COL] = SPACES;
char line3[MAX_COL] = SPACES;

if (utc_time[0] == ’ ’){ //Until we solve for time char* temp = "Acquiring Satellites";
for (int i = 0; i < MAX_COL; i++){
line3[i] = temp[i];
}
} else if (position_fix_indicator[0] != ’1’){ //Display time once we solve for time line2[0] = ’U’;
line2[1] = ’T’;
line2[2] = ’C’;
line2[3] = ’:’;
for (int i=0; i < GGA_UTC_BUFFER_SIZE; i++){ line2[4+i] = utc_time[i];
}

char* temp = "Getting PVT Solution"; for (int i = 0; i < MAX_COL; i++){ line3[i] = temp[i];
}
00172 | } else if (position_fix_indicator[0] == ’1’) { | //Once we get a fix, go into normal operation
| convertNMEAtoLLA();
| //Mode agnostic parts //line0 for (int i = 0; i < LLA_LAT_BUFFER_SIZE; i++){ line0[i] = latitudeLLA_str[i]; }
| line0[19] = ut_mode + ’0’; line0[18] = ’:’; line0[17] = ’e’; line0[16] = ’d’; line0[15] = ’o’; line0[14] = ’M’;

for (int i = 0; i < LLA_LONG_BUFFER_SIZE; i++){
| line1[i] = longitudeLLA_str[i]; }
| //mode-specific parts if (ut_mode == STAT_MODE){ //line1 line1[MAX_COL-8] = ’H’; line1[MAX_COL-7] = ’D’; line1[MAX_COL-6] = ’O’; line1[MAX_COL-5] = ’P’; line1[MAX_COL-4] = ’:’; line1[MAX_COL-3] = hdop[0]; line1[MAX_COL-2] = hdop[1]; line1[MAX_COL-1] = hdop[2];
| //line2 line2[0] = ’U’; line2[1] = ’T’; line2[2] = ’C’; line2[3] = ’:’;

for (int i=0; i < GGA_UTC_BUFFER_SIZE; i++){
| line2[4+i] = utc_time[i]; }
| line2[MAX_COL-1] = satellites_used[1]; line2[MAX_COL-2] = satellites_used[0]; line2[MAX_COL-3] = ’:’; line2[MAX_COL-4] = ’V’; line2[MAX_COL-5] = ’S’; line2[MAX_COL-6] = ’#’;
| //line3 line3[0] = ’V’; line3[1] = ’e’; line3[2] = ’l’; line3[3] = ’:’; //put vel here once we get it done TODO for (int i =0; i < 6; i++){ line3[4+i] = speed[i]; }
| line3[MAX_COL-9] = ’A’; line3[MAX_COL-8] = ’l’; line3[MAX_COL-7] = ’t’; for (int i = 0; i < 6; i ++){

3.11 G:/Project_Files/WayFindX/wfx_sw/wfx_sw/nf/nf.c File Reference | 17
00234 | line3[MAX_COL-6+i] = msl_altitude[i];
00235 | }
00236
00237 | }else { //if mode != STAT_MODE
00238 | //line 1
00239 | switch (ut_operation){
00240 | case SAVE_OP:
00241 | strncpy(line1+(MAX_COL-5), SAVE_STR, 5);
00242 | break;
00243 | case CLEAR_OP:
00244 | strncpy(line1+(MAX_COL-5), CLEAR_STR, 5);
00245 | break;
00246 | case RESET_OP:
00247 | strncpy(line1+(MAX_COL-5), RESET_STR, 5);
00248 | break;
00249 | default:
00250 | strncpy(line1+(MAX_COL-5), "Error", 5);
00251 | break;
00252 | }
00253 | //line2
00254 | line2[MAX_COL-4] = ’M’;
00255 | line2[MAX_COL-3] = ’e’;
00256 | line2[MAX_COL-2] = ’m’;
00257 | line2[MAX_COL-1] = ut_memory_0idx + ’0’;
00258
00259 | for (int i = 0; i < LLA_LAT_BUFFER_SIZE-2; i++){
00260 | line2[i] = ut_lat_mem_str[i];
00261 | }
00262 | for (int i = 0; i < LLA_LONG_BUFFER_SIZE; i++){
00263 | line3[i] = ut_long_mem_str[i];
00264 | }
00265
00266 | //line3
00267 | line3[MAX_COL-10]= ’D’;
00268 | line3[MAX_COL-9]= ’i’;
00269 | line3[MAX_COL-8]= ’s’;
00270 | line3[MAX_COL-7]= ’t’;
00271
00272
00273 | } //end mode checks
00274 | }//end else
00275
00276 | ds_print_string(line0, MAX_COL, 0);
00277 | ds_print_string(line1, MAX_COL, 1);
00278 | ds_print_string(line2, MAX_COL, 2);
00279 | ds_print_string(line3, MAX_COL, 3);
00280
00281
00282 } //end update display

## 3.11 G:/Project_Files/WayFindX/wfx_sw/wfx_sw/nf/nf.c File Reference

#include <avr/interrupt.h> #include <string.h>

#include <stdlib.h>

#include <stdint-gcc.h>

#include "nf.h"

#include "nf_types.h"

#include "../lib/uart.h"

#include "../ds/ds.h"

#include "../ut/utilities.h"

Macros

- #define F_CPU 4000000UL
- #define UART_BAUD_RATE 9600
- #define NMEA_MSG_ID_SIZE 5
- #define GGA_TYPE "GPGGA"
- #define GLL_TYPE "GPGLL"

### 18 File Documentation

- #define GSA_TYPE "GPGSA"
- #define GSV_TYPE "GPGSV"
- #define MSS_TYPE "GPMSS"
- #define RMC_TYPE "GPRMC"
- #define VTG_TYPE "GPVTG"
- #define ZDA_TYPE "GPZDA"
- #define OK_TO_SEND_TYPE "PSRF1"

Functions

- void nf_clear_nav_strings ()

Clear all navigation strings except UTC time.
- uint8_t nf_init ()

Initialize the navigation fetch module. This function initializes UART communication and clears navigation strings.
- void get_serial_char (char ∗outputchar)

Read a single character from the serial communication. This function blocks until a character is received.
- void read_nmea_msg_raw ()

Read a raw NMEA message from the serial communication. This function reads a raw NMEA message and processes GGA and VTG messages. Additionally, it polls buttons between messages.
- void convertNMEAtoLLA ()

Convert NMEA format coordinates to Latitude, Longitude, and Altitude (LLA) format. This function converts NMEA format coordinates to LLA format and stores them in global variables.

Variables

- char utc_time [GGA_UTC_BUFFER_SIZE]
- char latitude [GGA_LAT_BUFFER_SIZE]
- char ns_indicator [GGA_INDICATOR_SIZE]
- char longitude [GGA_LONG_BUFFER_SIZE]
- char ew_indicator [GGA_INDICATOR_SIZE]
- char position_fix_indicator [GGA_INDICATOR_SIZE]
- char satellites_used [GGA_SV_USD_BUFFER_SIZE]
- char hdop [GGA_HDOP_BUFFER_SIZE]
- char msl_altitude [GGA_ALTITUDE_BUFFER_SIZE]
- char speed [VTG_SPEED_BUFER_SIZE]
- float latitudeLLA_float
- float longitudeLLA_float
- float altitudeLLA_float
- char latitudeLLA_str [LLA_LAT_BUFFER_SIZE]
- char longitudeLLA_str [LLA_LONG_BUFFER_SIZE]
- char altitudeLLA_str [LLA_ALT_BUFFER_SIZE]

### 3.11.1 Macro Definition Documentation

### 3.11.1.1 F_CPU

#define F_CPU 4000000UL

Define the CPU frequency to 4MHz.

Definition at line 2 of file nf.c.

3.11 G:/Project_Files/WayFindX/wfx_sw/wfx_sw/nf/nf.c File Reference | 19

### 3.11.1.2 GGA_TYPE

#define GGA_TYPE "GPGGA"

Definition at line 20 of file nf.c.

### 3.11.1.3 GLL_TYPE

#define GLL_TYPE "GPGLL"

Definition at line 21 of file nf.c.

### 3.11.1.4 GSA_TYPE

#define GSA_TYPE "GPGSA"

Definition at line 22 of file nf.c.

### 3.11.1.5 GSV_TYPE

#define GSV_TYPE "GPGSV"

Definition at line 23 of file nf.c.

### 3.11.1.6 MSS_TYPE

#define MSS_TYPE "GPMSS"

Definition at line 24 of file nf.c.

### 3.11.1.7 NMEA_MSG_ID_SIZE

#define NMEA_MSG_ID_SIZE 5

Definition at line 17 of file nf.c.

### 3.11.1.8 OK_TO_SEND_TYPE

#define OK_TO_SEND_TYPE "PSRF1"

Definition at line 28 of file nf.c.

### 3.11.1.9 RMC_TYPE

#define RMC_TYPE "GPRMC"

Definition at line 25 of file nf.c.

### 20 File Documentation

### 3.11.1.10 UART_BAUD_RATE

#define UART_BAUD_RATE 9600

Definition at line 16 of file nf.c.

### 3.11.1.11 VTG_TYPE

#define VTG_TYPE "GPVTG"

Definition at line 26 of file nf.c.

### 3.11.1.12 ZDA_TYPE

#define ZDA_TYPE "GPZDA"

Definition at line 27 of file nf.c.

### 3.11.2 Function Documentation

### 3.11.2.1 convertNMEAtoLLA()

void convertNMEAtoLLA ( )

Convert NMEA format coordinates to Latitude, Longitude, and Altitude (LLA) format. This function converts NMEA format coordinates to LLA format and stores them in global variables.

Convert NMEA format coordinates to Latitude, Longitude, and Altitude (LLA) format.

Definition at line 334 of file nf.c.

### 3.11.2.2 get_serial_char()

void get_serial_char (

char ∗ outputchar )

Read a single character from the serial communication. This function blocks until a character is received.

Read a single character from the serial communication.

Parameters

outputchar Pointer to the character variable to store the read character.

Definition at line 114 of file nf.c.

3.11 G:/Project_Files/WayFindX/wfx_sw/wfx_sw/nf/nf.c File Reference | 21

### 3.11.2.3 nf_clear_nav_strings()

void nf_clear_nav_strings ( )

Clear all navigation strings except UTC time.

Definition at line 60 of file nf.c.

### 3.11.2.4 nf_init()

uint8_t nf_init ( )

Initialize the navigation fetch module. This function initializes UART communication and clears navigation strings.

Initialize the navigation fetch module.

Returns

0 if initialization is successful, otherwise returns 1.

Definition at line 82 of file nf.c.

### 3.11.2.5 read_nmea_msg_raw()

void read_nmea_msg_raw ( )

Read a raw NMEA message from the serial communication. This function reads a raw NMEA message and processes GGA and VTG messages. Additionally, it polls buttons between messages.

Read a raw NMEA message from the serial communication and extracts relevant data.

Definition at line 176 of file nf.c.

### 3.11.3 Variable Documentation

### 3.11.3.1 altitudeLLA_float

float altitudeLLA_float

Altitude in meters

Definition at line 45 of file nf.c.

### 3.11.3.2 altitudeLLA_str

char altitudeLLA_str[LLA_ALT_BUFFER_SIZE]

Altitude in meters

Definition at line 48 of file nf.c.

### 22 File Documentation

### 3.11.3.3 ew_indicator

char ew_indicator[GGA_INDICATOR_SIZE]

E/W Indicator, 'E' for east or 'W' for west

Definition at line 36 of file nf.c.

### 3.11.3.4 hdop

char hdop[GGA_HDOP_BUFFER_SIZE]

HDOP (Horizontal Dilution of Precision), e.g., "1.0"

Definition at line 39 of file nf.c.

### 3.11.3.5 latitude

char latitude[GGA_LAT_BUFFER_SIZE]

Latitude, e.g., "3723.2475"

Definition at line 33 of file nf.c.

### 3.11.3.6 latitudeLLA_float

float latitudeLLA_float

Latitude in degrees

Definition at line 43 of file nf.c.

### 3.11.3.7 latitudeLLA_str

char latitudeLLA_str[LLA_LAT_BUFFER_SIZE]

Latitude in degrees

Definition at line 46 of file nf.c.

### 3.11.3.8 longitude

char longitude[GGA_LONG_BUFFER_SIZE]

Longitude, e.g., "12158.3416"

Definition at line 35 of file nf.c.

3.11 G:/Project_Files/WayFindX/wfx_sw/wfx_sw/nf/nf.c File Reference | 23

### 3.11.3.9 longitudeLLA_float

float longitudeLLA_float

Longitude in degrees

Definition at line 44 of file nf.c.

### 3.11.3.10 longitudeLLA_str

char longitudeLLA_str[LLA_LONG_BUFFER_SIZE]

Longitude in degrees

Definition at line 47 of file nf.c.

### 3.11.3.11 msl_altitude

char msl_altitude[GGA_ALTITUDE_BUFFER_SIZE]

Mean Sea Level Altitude, e.g., "1.0"

Definition at line 40 of file nf.c.

### 3.11.3.12 ns_indicator

char ns_indicator[GGA_INDICATOR_SIZE]

N/S Indicator, 'N' for north or 'S' for south

Definition at line 34 of file nf.c.

### 3.11.3.13 position_fix_indicator

char position_fix_indicator[GGA_INDICATOR_SIZE]

Position Fix Indicator, see Table 1-4

Definition at line 37 of file nf.c.

### 3.11.3.14 satellites_used

char satellites_used[GGA_SV_USD_BUFFER_SIZE]

Satellites Used, range 0 to 12 eg 07

Definition at line 38 of file nf.c.

### 24 File Documentation

### 3.11.3.15 speed

char speed[VTG_SPEED_BUFER_SIZE]

Speed, e.g., "0.0"

Definition at line 41 of file nf.c.

### 3.11.3.16 utc_time

char utc_time[GGA_UTC_BUFFER_SIZE]

UTC Time, e.g., "161229.487"

Definition at line 32 of file nf.c.

## 3.12 nf.c

Go to the documentation of this file.

00001 #ifndef F_CPU
00002 #define F_CPU 4000000UL 00003 #endif
00004
00005 #include <avr/interrupt.h> 00006 #include <string.h>
00007 #include <stdlib.h>
00008 #include <stdint-gcc.h> 00009 #include "nf.h"
00010 #include "nf_types.h"
00011 #include "../lib/uart.h" 00012 #include "../ds/ds.h"
00013 #include "../ut/utilities.h" 00014
00015 //defines
00016 #define UART_BAUD_RATE 9600
00017 #define NMEA_MSG_ID_SIZE 5
00018
00019 //NMEA message IDs from NMEA documentation 00020 #define GGA_TYPE "GPGGA"
00021 #define GLL_TYPE "GPGLL"
00022 #define GSA_TYPE "GPGSA"
00023 #define GSV_TYPE "GPGSV" 00024 #define MSS_TYPE "GPMSS" 00025 #define RMC_TYPE "GPRMC"
00026 #define VTG_TYPE "GPVTG"
00027 #define ZDA_TYPE "GPZDA"
00028 #define OK_TO_SEND_TYPE "PSRF1" 00029
00030 //global
00031 //GGA MESSAGE
00032 char utc_time[GGA_UTC_BUFFER_SIZE]; 00033 char latitude[GGA_LAT_BUFFER_SIZE]; 00034 char ns_indicator[GGA_INDICATOR_SIZE];
00035 char longitude[GGA_LONG_BUFFER_SIZE];
00036 char ew_indicator[GGA_INDICATOR_SIZE];
00037 char position_fix_indicator[GGA_INDICATOR_SIZE]; 00038 char satellites_used[GGA_SV_USD_BUFFER_SIZE]; 00039 char hdop[GGA_HDOP_BUFFER_SIZE];
00040 char msl_altitude[GGA_ALTITUDE_BUFFER_SIZE]; 00041 char speed[VTG_SPEED_BUFER_SIZE];
00043 float latitudeLLA_float;
00044 float longitudeLLA_float;
00045 float altitudeLLA_float;
00046 char latitudeLLA_str[LLA_LAT_BUFFER_SIZE]; 00047 char longitudeLLA_str[LLA_LONG_BUFFER_SIZE]; 00048 char altitudeLLA_str[LLA_ALT_BUFFER_SIZE];
00050 //local static
00051 static char nmea_msg_id_buffer[NMEA_MSG_ID_SIZE]; 00052 static char gga_msg_buffer[GGA_SIZE];
00055 //function definitions
00056

3.12 nf.c | 25

00060 void nf_clear_nav_strings(){
00061 | memset(nmea_msg_id_buffer,0,sizeof(char)*NMEA_MSG_ID_SIZE); //zeroize
00062 | memset(gga_msg_buffer, ’ ’,sizeof(char)*GGA_SIZE); //zeroize msg buffer
00063 | memset(latitude, ’ ’, GGA_LAT_BUFFER_SIZE * sizeof(char));
00064 | memset(ns_indicator, ’ ’, GGA_INDICATOR_SIZE * sizeof(char));
00065 | memset(longitude, ’ ’, GGA_LONG_BUFFER_SIZE * sizeof(char));
00066 | memset(ew_indicator, ’ ’, GGA_INDICATOR_SIZE * sizeof(char));
00067 | memset(position_fix_indicator, ’ ’, GGA_INDICATOR_SIZE * sizeof(char));
00068 | memset(satellites_used, ’ ’, GGA_SV_USD_BUFFER_SIZE * sizeof(char));
00069 | memset(hdop, ’ ’, GGA_HDOP_BUFFER_SIZE * sizeof(char));
00070 | memset(msl_altitude, ’ ’, GGA_ALTITUDE_BUFFER_SIZE * sizeof(char));
00071
00072 | memset(latitudeLLA_str, ’ ’, LLA_LAT_BUFFER_SIZE * sizeof(char));
00073 | memset(longitudeLLA_str, ’ ’, LLA_LONG_BUFFER_SIZE * sizeof(char));
00074 | memset(altitudeLLA_str, ’ ’, LLA_ALT_BUFFER_SIZE * sizeof(char));
00075 }
00076
00082 uint8_t nf_init(){
00083 | cli();
00084 | /*
00085 | * | Initialize UART library, pass baudrate and AVR cpu clock
00086 | * | with the macro
00087 | * | UART_BAUD_SELECT() (normal speed mode )
00088 | * | or
00089 | * | UART_BAUD_SELECT_DOUBLE_SPEED() ( double speed mode)
00090 | */
00091 | uart_init( UART_BAUD_SELECT(UART_BAUD_RATE,F_CPU) );
00092
00093 | // Initialize the arrays within gga_msg
00094 | memset(utc_time, ’ ’, GGA_UTC_BUFFER_SIZE * sizeof(char));
00095 | memset(speed, ’ ’, VTG_SPEED_BUFER_SIZE * sizeof(char));
00096
00097 | nf_clear_nav_strings();
00098
00099
00100 | latitudeLLA_float = 0;
00101 | longitudeLLA_float = 0;
00102 | altitudeLLA_float = 0;
00103
00104
00105 | sei(); //UART is interrupt based;
00106 | return NF_INIT_SUCCESS;
00107 }
00108
00114 void get_serial_char(char* outputchar){
00115 | unsigned int c;
00116 | while (1){
00117 | /*
00118 | * Get received character from ringbuffer
00119 | * uart_getc() returns in the lower byte the received character and
00120 | * in the higher byte (bitmask) the last receive error
00121 | * UART_NO_DATA is returned when no data is available.
00122 | *
00123 | */
00124 | c = uart_getc();
00125 | if (!( c & UART_NO_DATA ))
00126 | {
00127 | /*
00128 | * new data available from UART
00129 | * check for Frame or Overrun error
00130 | */
00131 | #ifdef __DEBUG__
00132 | if ( c & UART_FRAME_ERROR )
00133 | {
00134 | /* Framing Error detected, i.e no stop bit detected */
00135 | #ifdef _DEBUG_
00136 | char* output = "NF Frame Error! ";
00137 | ds_print_string(output, 16, 0);
00138 | #endif
00139 | }
00140 | if ( c & UART_OVERRUN_ERROR )
00141 | {
00142 | /*
00143 | * Overrun, a character already present in the UART UDR register was
00144 | * not read by the interrupt handler before the next character arrived,
00145 | * one or more received characters have been dropped
00146 | */
00147 | char* output = " | OR ER";
00148 | ds_print_string(output, 16, 0);
00149 | }
00150 | if ( c & UART_BUFFER_OVERFLOW )
00151 | {
00152 | /*
00153 | * We are not reading the receive buffer fast enough,
00154 | * one or more received character have been dropped
00155 | */
00156 | char* output = "OF ER";

### 26 File Documentation

ds_print_string(output, 5, 0); }
#endif

/*
* send received character back */
*outputchar = (unsigned char)c; return;
}
}

00169 }

00176 void read_nmea_msg_raw(){ //nf_clear_nav_strings();
char tempChar;
do {
get_serial_char(&tempChar);
} while (tempChar != ’$’);

for (int i = 0; i < NMEA_MSG_ID_SIZE; i++){ get_serial_char(nmea_msg_id_buffer + i); }
get_serial_char(&tempChar); //eat comma

int counter = 0; //common counter to save memory alloc time //-----------------------------------------------------------------//only need GGA and VTG for requirements. Drop others if(strcmp(nmea_msg_id_buffer, GGA_TYPE) == 0){
//scrape raw
for (counter = 0; counter < GGA_SIZE; counter ++){ get_serial_char(gga_msg_buffer+counter);
}
//process message
int offset = 0;
//grab UTC if available
if (gga_msg_buffer[offset] != ’,’){
for (int i =0; i < GGA_UTC_BUFFER_SIZE; i++){ utc_time[i] = gga_msg_buffer[offset++];
}
//ds_print_string(utc_time, GGA_UTC_BUFFER_SIZE, 0); }else{ //otherwise skip comma from if statement offset++;
}
offset++;// skip comma

//grab LAT if available
if (gga_msg_buffer[offset] != ’,’){
for (int i =0; i < GGA_LAT_BUFFER_SIZE; i++){ latitude[i] = gga_msg_buffer[offset++];
}

//ds_print_string(latitude, GGA_LAT_BUFFER_SIZE, 0); }else{ //otherwise skip comma from if statement offset++;
}
offset++; // skip comma

//grab NS indicator if available
if (gga_msg_buffer[offset] != ’,’){
ns_indicator[0] = gga_msg_buffer[offset++]; //ds_print_string(ew_indicator, GGA_INDICATOR_SIZE, 1); }else{ //otherwise skip comma from if statement
offset++;
}
offset++; // skip comma

//grab LONG if available
if (gga_msg_buffer[offset] != ’,’){
for (int i =0; i < GGA_LONG_BUFFER_SIZE; i++){ longitude[i] = gga_msg_buffer[offset++];
}
//ds_print_string(longitude, GGA_LONG_BUFFER_SIZE, 1); }else{ //otherwise skip comma from if statement offset++;
}
offset++; // skip comma

//grab EW indicator if available
if (gga_msg_buffer[offset] != ’,’){
for (int i =0; i < GGA_INDICATOR_SIZE; i++){ ew_indicator[i] = gga_msg_buffer[offset++];
}
//ds_print_string(ew_indicator, GGA_INDICATOR_SIZE, 1); }else{ //otherwise skip comma from if statement

3.12 nf.c | 27

offset++;
}
offset++; // skip comma

//grab FIX indicator if available
if (gga_msg_buffer[offset] != ’,’){
for (int i =0; i < GGA_INDICATOR_SIZE; i++){ position_fix_indicator[i] = gga_msg_buffer[offset++];
}
//ds_print_string(position_fix_indicator, GGA_INDICATOR_SIZE, 1); }else{ //otherwise skip comma from if statement
offset++;
}
offset++; // skip comma

//grab NUM_SV if available
if (gga_msg_buffer[offset] != ’,’){
for (int i =0; i < GGA_SV_USD_BUFFER_SIZE; i++){ satellites_used[i] = gga_msg_buffer[offset++];
}
//ds_print_string(satellites_used, GGA_SV_USD_BUFFER_SIZE, 1); }else{ //otherwise skip comma from if statement
offset++;
}
offset++; // skip comma

//grab HDOP if available
if (gga_msg_buffer[offset] != ’,’){
for (int i =0; i < GGA_HDOP_BUFFER_SIZE; i++){ hdop[i] = gga_msg_buffer[offset++];
}
//ds_print_string(hdop, GGA_HDOP_BUFFER_SIZE, 0); }else{ //otherwise skip comma from if statement offset++;
}
offset++;
//end of known sizes. Alt is dynamic tempChar = 0;
int i = 0;
get_serial_char(&tempChar);//eat comma get_serial_char(&tempChar);
while ((tempChar != ’,’) && (i < GGA_ALTITUDE_BUFFER_SIZE)){ msl_altitude[i++] = tempChar; get_serial_char(&tempChar);
}

} //END GGA
else if (strcmp(nmea_msg_id_buffer, VTG_TYPE) == 0){
for (uint8_t comma_counter = 6; comma_counter >0; comma_counter--){ do{
get_serial_char(&tempChar);
} while (tempChar != ’,’);
}
memset(speed, ’ ’, VTG_SPEED_BUFER_SIZE * sizeof(char)); //should be at speed now
int i = 0;
get_serial_char(&tempChar);//eat comma
while ((tempChar != ’,’) && (i < VTG_SPEED_BUFER_SIZE)){ speed[i++] = tempChar;
get_serial_char(&tempChar);
}

}//end VTG msg

//poll buttons between messages //ut_poll_btns();
00325 }

00334 void convertNMEAtoLLA() { // Convert latitude from NMEA format to degrees double deg = 0.0;
double min = 0.0;

// Convert the latitude from degrees and minutes to degree decimal char tempBuffer[9] = {0};
for (int i = 0; i < 8; i++){
tempBuffer[i] = latitude[2+i];
}
min = atof(tempBuffer);

deg += (1.0 * (latitude[GGA_LAT_BUFFER_SIZE - 9] - ’0’)); deg += (10.0 * (latitude[GGA_LAT_BUFFER_SIZE - 10] - ’0’));

### 28 File Documentation

latitudeLLA_float = deg + (min / 60.0f); // Combine degrees and minutes

// Extract integer and decimal parts
uint16_t integer_part = (uint16_t)latitudeLLA_float;
float fractional_part = latitudeLLA_float - integer_part; uint32_t decimal_part = (uint32_t)(fractional_part * 100000);

// Convert integer part to string
latitudeLLA_str[1] = ’0’ + ((integer_part / 10) % 10); // Tens latitudeLLA_str[2] = ’0’ + (integer_part % 10); // Ones

// Decimal point
latitudeLLA_str[3] = ’.’;

// Convert decimal part to string
latitudeLLA_str[4] = ’0’ + ((decimal_part / 10000) % 10); // Ten-thousands latitudeLLA_str[5] = ’0’ + ((decimal_part / 1000)% 10); // Thousands latitudeLLA_str[6] = ’0’ + ((decimal_part / 100) % 10); // Hundreds latitudeLLA_str[7] = ’0’ + ((decimal_part / 10) % 10); // Tens latitudeLLA_str[8] = ’0’ + (decimal_part % 10); // Ones

if (ns_indicator[0] ==’S’){
latitudeLLA_str[0] = ’-’;
latitudeLLA_float *= -1;
} else{
latitudeLLA_str[0] = ’+’;
}

//long
deg = 0.0;
min = 0.0;

// Convert the longitude from degrees and minutes to degree decimal char tempBuffer2[9] = {0};
for (int i = 0; i < 8; i++){
tempBuffer2[i] = longitude[3+i];
}
min = atof(tempBuffer2);

deg += (1.0 * (longitude[2] - ’0’)); deg += (10.0 * (longitude[1] - ’0’));
deg += (100.0 * (longitude[0] - ’0’));

longitudeLLA_float = deg + (min / 60.0f); // Combine degrees and minutes

// Extract integer and decimal parts
integer_part = (uint16_t)longitudeLLA_float;
fractional_part = longitudeLLA_float - integer_part; decimal_part = (uint32_t)(fractional_part * 100000);

// Convert integer part to string
longitudeLLA_str[1] = ’0’ + ((integer_part / 100) % 10); // Hundreds longitudeLLA_str[2] = ’0’ + ((integer_part / 10) % 10); // Tens longitudeLLA_str[3] = ’0’ + (integer_part % 10); // Ones

// Decimal point
longitudeLLA_str[4] = ’.’;

// Convert decimal part to string
longitudeLLA_str[5] = ’0’ + ((decimal_part / 10000) % 10); // Ten-thousands longitudeLLA_str[6] = ’0’ + ((decimal_part / 1000)% 10); // Thousands longitudeLLA_str[7] = ’0’ + ((decimal_part / 100) % 10); // Hundreds longitudeLLA_str[8] = ’0’ + ((decimal_part / 10) % 10); // Tens longitudeLLA_str[9] = ’0’ + (decimal_part % 10); // Ones

if (ns_indicator[0] ==’S’){
longitudeLLA_str[0] = ’-’;
latitudeLLA_float *= -1;
} else{
longitudeLLA_str[0] = ’+’;
}

altitudeLLA_float = atof(msl_altitude); 00424 }

## 3.13 G:/Project_Files/WayFindX/wfx_sw/wfx_sw/nf/nf.h File Reference

Header file containing common functions and definitions for the navigation fetch (NV) CSC.

3.13 G:/Project_Files/WayFindX/wfx_sw/wfx_sw/nf/nf.h File Reference | 29

#include "../ut/ut_types.h"

#include "../ds/ds.h"

Macros

- #define NF_INIT_SUCCESS 0
- #define NF_INIT_FAILURE 1

Functions

- uint8_t nf_init ()

Initialize the navigation fetch module.
- void get_serial_char (char ∗outputchar)

Read a single character from the serial communication.
- void read_nmea_msg_raw ()

Read a raw NMEA message from the serial communication and extracts relevant data.
- void convertNMEAtoLLA ()

Convert NMEA format coordinates to Latitude, Longitude, and Altitude (LLA) format.

### 3.13.1 Detailed Description

Header file containing common functions and definitions for the navigation fetch (NV) CSC.

This file provides declarations for common utility functions and definitions associated with NV

Definition in file nf.h.

### 3.13.2 Macro Definition Documentation

### 3.13.2.1 NF_INIT_FAILURE

#define NF_INIT_FAILURE 1

Definition at line 15 of file nf.h.

### 3.13.2.2 NF_INIT_SUCCESS

#define NF_INIT_SUCCESS 0

Definition at line 14 of file nf.h.

### 30 File Documentation

### 3.13.3 Function Documentation

### 3.13.3.1 convertNMEAtoLLA()

void convertNMEAtoLLA ( )

Convert NMEA format coordinates to Latitude, Longitude, and Altitude (LLA) format.

Convert NMEA format coordinates to Latitude, Longitude, and Altitude (LLA) format.

Definition at line 334 of file nf.c.

### 3.13.3.2 get_serial_char()

void get_serial_char (

char ∗ outputchar )

Read a single character from the serial communication.

3.14 nf.h | 31

Parameters

outputchar Pointer to the character variable to store the read character.

Read a single character from the serial communication.

Parameters

outputchar Pointer to the character variable to store the read character.

Definition at line 114 of file nf.c.

### 3.13.3.3 nf_init()

uint8_t nf_init ( )

Initialize the navigation fetch module.

Returns

0 if initialization is successful

Initialize the navigation fetch module.

Returns

0 if initialization is successful, otherwise returns 1.

Definition at line 82 of file nf.c.

### 3.13.3.4 read_nmea_msg_raw()

void read_nmea_msg_raw ( )

Read a raw NMEA message from the serial communication and extracts relevant data.

Read a raw NMEA message from the serial communication and extracts relevant data.

Definition at line 176 of file nf.c.

## 3.14 nf.h

Go to the documentation of this file.

00001
00008 #ifndef NF_H_
00009 #define NF_H_
00010
00011 #include "../ut/ut_types.h" 00012 #include "../ds/ds.h" 00013
00014 #define NF_INIT_SUCCESS 0 00015 #define NF_INIT_FAILURE 1 00016
00017
00022 uint8_t nf_init();
00023
00028 void get_serial_char(char* outputchar); 00029
00033 void read_nmea_msg_raw();
00034
00038 void convertNMEAtoLLA(); 00039
00040
00041 #endif /* NF_H_ */

### 32 File Documentation

## 3.15 G:/Project_Files/WayFindX/wfx_sw/wfx_sw/nf/nf_types.h File Reference

Macros

- #define GGA_INDICATOR_SIZE 1
- #define LLA_LONG_BUFFER_SIZE 10
- #define LLA_LAT_BUFFER_SIZE 11
- #define LLA_ALT_BUFFER_SIZE 6
- #define GGA_UTC_BUFFER_SIZE 9
- #define GGA_LAT_BUFFER_SIZE 10
- #define GGA_LONG_BUFFER_SIZE 11
- #define GGA_SV_USD_BUFFER_SIZE 2
- #define GGA_HDOP_BUFFER_SIZE 3
- #define GGA_NUM_INDICATORS_ACTIVE 3
- #define GGA_NUM_ITEMS_ACTIVE 8
- #define GGA_ALTITUDE_BUFFER_SIZE 7
- #define VTG_SPEED_BUFER_SIZE 7
- #define GGA_SIZE (GGA_UTC_BUFFER_SIZE + GGA_LAT_BUFFER_SIZE + GGA_LONG_BUFFER_SIZE + GGA_SV_USD_BUFFER_SIZE + GGA_HDOP_BUFFER_SIZE + GGA_NUM_INDICATORS_ACTIVE + GGA_NUM_ITEMS_ACTIVE)

Variables

- char utc_time [GGA_UTC_BUFFER_SIZE]
- char latitude [GGA_LAT_BUFFER_SIZE]
- char ns_indicator [GGA_INDICATOR_SIZE]
- char longitude [GGA_LONG_BUFFER_SIZE]
- char ew_indicator [GGA_INDICATOR_SIZE]
- char position_fix_indicator [GGA_INDICATOR_SIZE]
- char satellites_used [GGA_SV_USD_BUFFER_SIZE]
- char hdop [GGA_HDOP_BUFFER_SIZE]
- char msl_altitude [GGA_ALTITUDE_BUFFER_SIZE]
- float latitudeLLA_float
- float longitudeLLA_float
- float altitudeLLA_float
- char latitudeLLA_str [LLA_LAT_BUFFER_SIZE]
- char longitudeLLA_str [LLA_LONG_BUFFER_SIZE]
- char altitudeLLA_str [LLA_ALT_BUFFER_SIZE]
- char speed [VTG_SPEED_BUFER_SIZE]

### 3.15.1 Macro Definition Documentation

### 3.15.1.1 GGA_ALTITUDE_BUFFER_SIZE

#define GGA_ALTITUDE_BUFFER_SIZE 7

Size of the buffer for storing altitude in the GGA message

Definition at line 26 of file nf_types.h.

3.15 G:/Project_Files/WayFindX/wfx_sw/wfx_sw/nf/nf_types.h File Reference | 33

### 3.15.1.2 GGA_HDOP_BUFFER_SIZE

#define GGA_HDOP_BUFFER_SIZE 3

Size of the buffer for storing HDOP in the GGA message

Definition at line 23 of file nf_types.h.

### 3.15.1.3 GGA_INDICATOR_SIZE

#define GGA_INDICATOR_SIZE 1

Size of the N/S and E/W indicators in the GGA message

Definition at line 12 of file nf_types.h.

### 3.15.1.4 GGA_LAT_BUFFER_SIZE

#define GGA_LAT_BUFFER_SIZE 10

Size of the buffer for storing latitude in the GGA message

Definition at line 20 of file nf_types.h.

### 3.15.1.5 GGA_LONG_BUFFER_SIZE

#define GGA_LONG_BUFFER_SIZE 11

Size of the buffer for storing longitude in the GGA message

Definition at line 21 of file nf_types.h.

### 3.15.1.6 GGA_NUM_INDICATORS_ACTIVE

#define GGA_NUM_INDICATORS_ACTIVE 3

Number of active indicators in the GGA message

Definition at line 24 of file nf_types.h.

### 3.15.1.7 GGA_NUM_ITEMS_ACTIVE

#define GGA_NUM_ITEMS_ACTIVE 8

Number of active items in the GGA message

Definition at line 25 of file nf_types.h.

### 34 File Documentation

### 3.15.1.8 GGA_SIZE

#define GGA_SIZE (GGA_UTC_BUFFER_SIZE + GGA_LAT_BUFFER_SIZE + GGA_LONG_BUFFER_SIZE + GGA_SV_USD_BUFFER_SIZE

+ GGA_HDOP_BUFFER_SIZE + GGA_NUM_INDICATORS_ACTIVE + GGA_NUM_ITEMS_ACTIVE)

Total size of the GGA message

Definition at line 29 of file nf_types.h.

### 3.15.1.9 GGA_SV_USD_BUFFER_SIZE

#define GGA_SV_USD_BUFFER_SIZE 2

Size of the buffer for storing satellites used in the GGA message

Definition at line 22 of file nf_types.h.

### 3.15.1.10 GGA_UTC_BUFFER_SIZE

#define GGA_UTC_BUFFER_SIZE 9

Size of the buffer for storing UTC time in the GGA message

Definition at line 19 of file nf_types.h.

### 3.15.1.11 LLA_ALT_BUFFER_SIZE

#define LLA_ALT_BUFFER_SIZE 6

Size of the buffer for storing altitude in LLA format

Definition at line 16 of file nf_types.h.

### 3.15.1.12 LLA_LAT_BUFFER_SIZE

#define LLA_LAT_BUFFER_SIZE 11

Size of the buffer for storing latitude in LLA format

Definition at line 15 of file nf_types.h.

### 3.15.1.13 LLA_LONG_BUFFER_SIZE

#define LLA_LONG_BUFFER_SIZE 10

Size of the buffer for storing longitude in LLA format

Definition at line 14 of file nf_types.h.

3.15 G:/Project_Files/WayFindX/wfx_sw/wfx_sw/nf/nf_types.h File Reference | 35

### 3.15.1.14 VTG_SPEED_BUFER_SIZE

#define VTG_SPEED_BUFER_SIZE 7

Size of the buffer for storing speed in the VTG message

Definition at line 27 of file nf_types.h.

### 3.15.2 Variable Documentation

### 3.15.2.1 altitudeLLA_float

float altitudeLLA_float [extern]

Altitude in meters

Definition at line 45 of file nf.c.

### 3.15.2.2 altitudeLLA_str

char altitudeLLA_str[LLA_ALT_BUFFER_SIZE] [extern]

Altitude in meters

Definition at line 48 of file nf.c.

### 3.15.2.3 ew_indicator

char ew_indicator[GGA_INDICATOR_SIZE] [extern]

E/W Indicator, 'E' for east or 'W' for west

Definition at line 36 of file nf.c.

### 3.15.2.4 hdop

char hdop[GGA_HDOP_BUFFER_SIZE] [extern]

HDOP (Horizontal Dilution of Precision), e.g., "1.0"

Definition at line 39 of file nf.c.

### 3.15.2.5 latitude

char latitude[GGA_LAT_BUFFER_SIZE] [extern]

Latitude, e.g., "3723.24756"

Latitude, e.g., "3723.2475"

Definition at line 33 of file nf.c.

### 36 File Documentation

### 3.15.2.6 latitudeLLA_float

float latitudeLLA_float [extern]

Latitude in degrees

Definition at line 43 of file nf.c.

### 3.15.2.7 latitudeLLA_str

char latitudeLLA_str[LLA_LAT_BUFFER_SIZE] [extern]

Latitude in degrees

Definition at line 46 of file nf.c.

### 3.15.2.8 longitude

char longitude[GGA_LONG_BUFFER_SIZE] [extern]

Longitude, e.g., "12158.34166"

Longitude, e.g., "12158.3416"

Definition at line 35 of file nf.c.

### 3.15.2.9 longitudeLLA_float

float longitudeLLA_float [extern]

Longitude in degrees

Definition at line 44 of file nf.c.

### 3.15.2.10 longitudeLLA_str

char longitudeLLA_str[LLA_LONG_BUFFER_SIZE] [extern]

Longitude in degrees

Definition at line 47 of file nf.c.

### 3.15.2.11 msl_altitude

char msl_altitude[GGA_ALTITUDE_BUFFER_SIZE] [extern]

Altitude above sea level in meters one decimal of precision.

Mean Sea Level Altitude, e.g., "1.0"

Definition at line 40 of file nf.c.

3.15 G:/Project_Files/WayFindX/wfx_sw/wfx_sw/nf/nf_types.h File Reference | 37

### 3.15.2.12 ns_indicator

char ns_indicator[GGA_INDICATOR_SIZE] [extern]

N/S Indicator, 'N' for north or 'S' for south

Definition at line 34 of file nf.c.

### 3.15.2.13 position_fix_indicator

char position_fix_indicator[GGA_INDICATOR_SIZE] [extern]

Position Fix Indicator, see Table 1-4

Definition at line 37 of file nf.c.

### 3.15.2.14 satellites_used

char satellites_used[GGA_SV_USD_BUFFER_SIZE] [extern]

Satellites Used, range 0 to 12 eg 07

Definition at line 38 of file nf.c.

### 3.15.2.15 speed

char speed[VTG_SPEED_BUFER_SIZE] [extern]

Speed in km/hr

Speed, e.g., "0.0"

Definition at line 41 of file nf.c.

### 3.15.2.16 utc_time

char utc_time[GGA_UTC_BUFFER_SIZE] [extern]

UTC Time, e.g., "161229.487"

Definition at line 32 of file nf.c.

### 38 File Documentation

## 3.16 nf_types.h

Go to the documentation of this file.

00001 /*
00002 | * nf_types.h
00003 | * @brief Header file containing common types and definitions for the navigation fetch (NV) CSC.
00004 | *
00005 | * This file provides definitions for common data types and sizes associated with the NV CSC.
00006 | */
00007
00008
00009 #ifndef NF_TYPES_H_
00010 #define NF_TYPES_H_
00011
00012 #define GGA_INDICATOR_SIZE 1 00014 #define LLA_LONG_BUFFER_SIZE 10
00015 #define LLA_LAT_BUFFER_SIZE 11
00016 #define LLA_ALT_BUFFER_SIZE 6
00018 // Size definitions for components of the GGA message 00019 #define GGA_UTC_BUFFER_SIZE 9
00020 #define GGA_LAT_BUFFER_SIZE 10
00021 #define GGA_LONG_BUFFER_SIZE 11
00022 #define GGA_SV_USD_BUFFER_SIZE 2 00023 #define GGA_HDOP_BUFFER_SIZE 3 00024 #define GGA_NUM_INDICATORS_ACTIVE 3 00025 #define GGA_NUM_ITEMS_ACTIVE 8
00026 #define GGA_ALTITUDE_BUFFER_SIZE 7
00027 #define VTG_SPEED_BUFER_SIZE 7
00029 #define GGA_SIZE (GGA_UTC_BUFFER_SIZE + GGA_LAT_BUFFER_SIZE + GGA_LONG_BUFFER_SIZE +
| GGA_SV_USD_BUFFER_SIZE + GGA_HDOP_BUFFER_SIZE + GGA_NUM_INDICATORS_ACTIVE + GGA_NUM_ITEMS_ACTIVE)
00031 extern char utc_time[GGA_UTC_BUFFER_SIZE];
00032 extern char latitude[GGA_LAT_BUFFER_SIZE];
00033 extern char ns_indicator[GGA_INDICATOR_SIZE];
00034 extern char longitude[GGA_LONG_BUFFER_SIZE];
00035 extern char ew_indicator[GGA_INDICATOR_SIZE];
00036 extern char position_fix_indicator[GGA_INDICATOR_SIZE]; 00037 extern char satellites_used[GGA_SV_USD_BUFFER_SIZE]; 00038 extern char hdop[GGA_HDOP_BUFFER_SIZE];
00039 extern char msl_altitude[GGA_ALTITUDE_BUFFER_SIZE]; 00041 extern float latitudeLLA_float;
00042 extern float longitudeLLA_float;
00043 extern float altitudeLLA_float;
00045 extern char latitudeLLA_str[LLA_LAT_BUFFER_SIZE]; 00046 extern char longitudeLLA_str[LLA_LONG_BUFFER_SIZE]; 00047 extern char altitudeLLA_str[LLA_ALT_BUFFER_SIZE]; 00049 extern char speed[VTG_SPEED_BUFER_SIZE];
00051 #endif /* NF_TYPES_H_ */
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

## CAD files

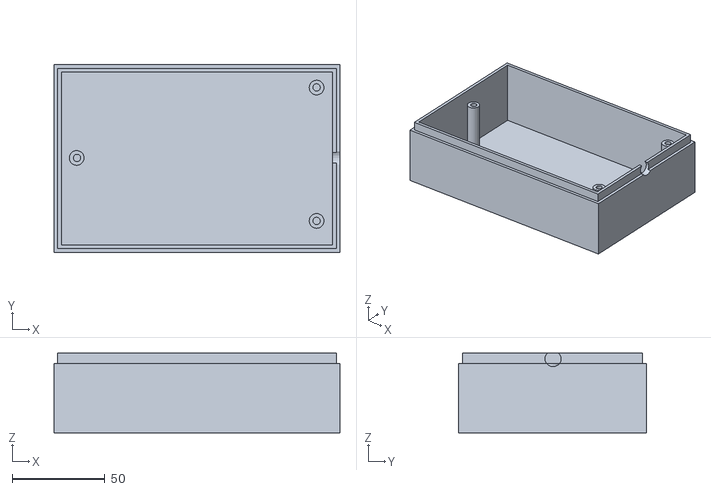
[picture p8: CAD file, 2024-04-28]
docs/3D_designs/WayFindX_BOTTOM.stl
154.0 x 101.0 x 43.0

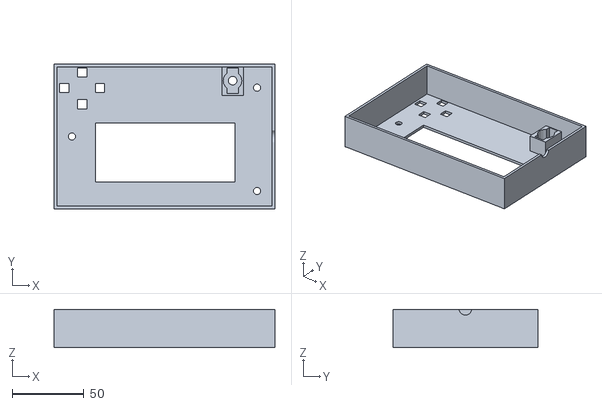
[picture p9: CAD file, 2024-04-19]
docs/3D_designs/WayFindX_TOP.stl
154.0 x 101.0 x 26.7

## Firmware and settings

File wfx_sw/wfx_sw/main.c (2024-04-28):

/**
 * @file wfx_sw.c
 * @brief Control system for an Arduino-based setup featuring a GPS module, buttons, and a 20x4 LCD.
 *
 * WayFindX - Device that allows user to track up to 10 GPS locations at once, calculating 
 * distance between the user and one location at a time.
 *
 * @author "Avengers Assembly" - Abele Atresso and Bradley Johnson
 * @date: 2024/04/24
 */ 

/**
 * @mainpage WayFindX
 * @brief Synopsis of the WayFindX Embedded Systems Project.
 *
 * WayFindX is a handheld GPS receiver project developed by Avengers Assembly, consisting of Bradley Johnson and Abele Atresso. The project aims to create a portable navigation device that enhances outdoor navigation capabilities for users such as hikers, adventurers, and outdoor enthusiasts. WayFindX provides essential features including position and velocity tracking, storage of multiple locations, and distance calculation to selected stored positions.
 *
 * @section features Key Features
 * - Display of user position and velocity information
 * - Storage of multiple locations for navigation
 * - Calculation of distance to selected stored positions
 * - Intuitive user interface with control buttons and LCD display
 *
 * @section hardware Hardware Components
 * The project utilizes the following hardware components:
 * - Arduino microcontroller (ATMega328p)
 * - HD44780 Controlled 20x4 LCD for display
 * - Control Stick for user input
 * - NEO-6M GPS module for positioning
 * - Power Switch and 9V battery for power management
 * - Additional components for connectivity
 * - Custom-designed 3D printed case for enclosure
 *
 * @section software Software Interface
 * WayFindX provides a user-friendly interface with control buttons for navigation and interaction. The software is designed to display essential information such as current position, stored locations, and operational modes on the LCD display. Users can cycle through saved positions, select operations, and execute actions with ease.
 *
 * @section challenges Challenges Faced
 * The project encountered various challenges including serial communication, interfacing with new ICs, soldering, and enclosure design. Overcoming these challenges required careful planning, experimentation, and troubleshooting.
 *
 * For detailed documentation and code implementation, refer to the project source code and comments.\
 * @version 1.0
 * @copyright (C) 2024 Bradley Johnson and Abele Atresso
 */

#ifndef F_CPU
#define F_CPU 4000000UL /**< Define the CPU frequency to 4MHz. */
#endif

//PORT Pin 2 PD2
#include <avr/power.h>
#include <avr/io.h>
#include <util/delay.h>
#include <stdlib.h>

#include "ds/ds.h" /**< Include display-related functions. */
#include "ir/ir.h" /**< Include interrupt routines. */
#include "nf/nf.h"  /**< Include navigation fetch functions */
#include "nf/nf_types.h"
#include "ut/utilities.h" /**< Include utility functions. */
#include "ut/ut_types.h" /**< Include common type definitions. */
#include <string.h>

void startup();
void task_1hz();
void update_display();


/**
 * @brief Main loop function.
 *
 * This function controls the program flow and will not return.
 * It initializes the peripherals, clears the display, and continuously updates the system behavior.
 */
int main(void)
{
	startup();
    /* Main loop */
    while (1){
		//read_nmea_msg
		read_nmea_msg_raw();
		if (ir_trigger_1hz_flag_g == true){
			task_1hz();
			ir_trigger_1hz_flag_g = false;
		}
	}
}


/**
 * @brief Performs startup initialization.
 *
 * This function initializes various peripherals and components during startup, such as the display, interrupt routines, navigation fetch, and utilities.
 */
void startup(){
	//Initialize
	// Set clock pre-scaler to divide by 4
	clock_prescale_set(clock_div_4);
			
	// Initialize computer software components (CSC's)
	ds_init(); /**< Initialize display CSC. */
	{
		char* welcome = "- - - - ~~~~ - - - -";
		ds_print_string(welcome, MAX_COL, 0);
	}
	{ //Welcome Screen - limited scope
		char* welcome = "- - - WayFindX - - -";
		ds_print_string(welcome, MAX_COL, 1);
	}
	{
		char* welcome = "- - - - ~~~~ - - - -";
		ds_print_string(welcome, MAX_COL, 2);
	}
	_delay_ms(0.1f);
		
	ir_init(); /**< Initialize interrupt routines. */
	_delay_ms(0.1f);
	if (nf_init()){ /**<Initialize navigation fetch CSC. */
		char* err = "  Nav init failure  ";
		ds_print_string(err, MAX_COL, 1);
		while(1){};
	}
	_delay_ms(0.6f);
	ut_init(); /**< Initialize utilities CSC. */
}

/**
 * @brief Executes tasks that should occur every 1Hz.
 *
 * This function is called once per second and performs tasks such as updating the display.
 */
void task_1hz(){
	//Condition where USART if out of sync with NEO6-M
	if ((position_fix_indicator[0] == '1') && (speed[0] == ' ') && (speed[1] == ' ')){
		/* Re-Initialize navigation fetch CSC. */
		do {
			char* err = "Nav module off sync!";
			ds_print_string(err, MAX_COL, 1);
		} while(nf_init());
	}else if(ut_mode == NAV_MODE) {
		//if not corrupted; do distance calculation if in nav mode
		ut_update_dist();
	}
	update_display();
}

/**
 * @brief Updates the display with relevant information.
 *
 * This function updates the display with information such as GPS coordinates, mode, operation, and memory status.
 */
void update_display(){
	char line0[MAX_COL] = SPACES;
	char line1[MAX_COL] = SPACES;  
	char line2[MAX_COL] = SPACES;
	char line3[MAX_COL] = SPACES;

	if (utc_time[0] == ' '){ //Until we solve for time
		char counter[7];
		itoa(ir_sec_counter, counter, 10);
		line0[0] = 'T';
		line0[1] = 'T';
		line0[2] = 'F';
		line0[3] = 'F';
		line0[4] = ':';
		for (int i = 0; i < 7; i++){
			if (counter[i] == 0){
				break;
			}
			line0[i+5] = counter[i];
		}
		
		char* temp = "Acquiring Satellites";
		for (int i = 0; i < MAX_COL; i++){
			line3[i] = temp[i];
		}		
	} else if (position_fix_indicator[0] != '1'){ //Display time once we solve for time
		char counter[7];
		itoa(ir_sec_counter, counter, 10);
		line0[0] = 'T';
		line0[1] = 'T';
		line0[2] = 'F';
		line0[3] = 'F';
		line0[4] = ':';
		for (int i = 0; i < 7; i++){
			if (counter[i] == 0){
				break;
			}
			line0[i+5] = counter[i];
		}
				
		line2[0] = 'U';
		line2[1] = 'T';
		line2[2] = 'C';
		line2[3] = ':';
		for (int i=0; i < GGA_UTC_BUFFER_SIZE; i++){
			line2[4+i] = utc_time[i];
		}
		
		char* temp = "Getting PVT Solution";
		for (int i = 0; i < MAX_COL; i++){
			line3[i] = temp[i];
		}
		
	} else if (position_fix_indicator[0] == '1') {	//Once we get a fix, go into normal operation
		convertNMEAtoLLA();
		
		//Mode agnostic parts
		//line0
		for (int i = 0; i < LLA_LAT_BUFFER_SIZE; i++){
			line0[i] = latitudeLLA_str[i];
		}
		
		line0[19] = ut_mode + '0';
		line0[18] = ':';
		line0[17] = 'e';
		line0[16] = 'd';
		line0[15] = 'o';
		line0[14] = 'M';
		
		for (int i = 0; i < LLA_LONG_BUFFER_SIZE; i++){
			line1[i] = longitudeLLA_str[i];
		}
		
		//mode-specific parts
		if (ut_mode == STAT_MODE){
			//line1
			line1[MAX_COL-8] = 'H';
			line1[MAX_COL-7] = 'D';
			line1[MAX_COL-6] = 'O';
			line1[MAX_COL-5] = 'P';
			line1[MAX_COL-4] = ':';
			line1[MAX_COL-3] = hdop[0];
			line1[MAX_COL-2] = hdop[1];
			line1[MAX_COL-1] = hdop[2];
			
			//line2 
			line2[0] = 'U';
			line2[1] = 'T';
			line2[2] = 'C';
			line2[3] = ':';
			for (int i=0; i < GGA_UTC_BUFFER_SIZE; i++){
				line2[4+i] = utc_time[i];
			}
			
			line2[MAX_COL-1] = satellites_used[1];
			line2[MAX_COL-2] = satellites_used[0];
			line2[MAX_COL-3] = ':';
			line2[MAX_COL-4] = 'V';
			line2[MAX_COL-5] = 'S';
			line2[MAX_COL-6] = '#';
			
			//line3
			line3[0] = 'V';
			line3[1] = 'e';
			line3[2] = 'l';
			line3[3] = ':';
			//put vel here once we get it done TODO
			for (int i =0; i < 6; i++){
				line3[4+i] = speed[i];
			}
			
			line3[MAX_COL-9] = 'A';
			line3[MAX_COL-8] = 'l';
			line3[MAX_COL-7] = 't';
			for (int i = 0; i < 6; i ++){
				line3[MAX_COL-6+i] = msl_altitude[i];
			}
			
		}else { //if mode != STAT_MODE
			//line 1
			switch (ut_operation){
				case SAVE_OP:
					strncpy(line1+(MAX_COL-5), SAVE_STR, 5);
					break;
				case CLEAR_OP:
					strncpy(line1+(MAX_COL-5), CLEAR_STR, 5);
					break;
				case RESET_OP:
					strncpy(line1+(MAX_COL-5), RESET_STR, 5);
					break;
				default:
					strncpy(line1+(MAX_COL-5), "Error", 5);
					break; 
			}
			//line2
			line2[MAX_COL-4] = 'M';
			line2[MAX_COL-3] = 'e';
			line2[MAX_COL-2] = 'm';
			line2[MAX_COL-1] = ut_memory_0idx + '0';
			
			for (int i = 0; i < LLA_LAT_BUFFER_SIZE-2; i++){
				line2[i] = ut_lat_mem_str[i];
			}
			for (int i = 0; i < LLA_LONG_BUFFER_SIZE; i++){
				line3[i] = ut_long_mem_str[i];
			}

			//line3
			line3[MAX_COL-10]= 'D';
			line3[MAX_COL-9]= 'i';
			line3[MAX_COL-8]= 's';
			line3[MAX_COL-7]= 't';
			for (int i = 0; i < DISTANCE_SIG_FIG; i++){
				line3[MAX_COL-(6-i)] = ut_distance_str[i];
			}
		} //end mode checks (stat mode)
	}//end normal operation
	
	ds_print_string(line0, MAX_COL, 0);
	ds_print_string(line1, MAX_COL, 1);
	ds_print_string(line2, MAX_COL, 2);
	ds_print_string(line3, MAX_COL, 3);
	
} //end update display

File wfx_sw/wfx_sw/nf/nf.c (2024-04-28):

#ifndef F_CPU
#define F_CPU 4000000UL /**< Define the CPU frequency to 4MHz. */
#endif

#include <avr/interrupt.h>
#include <string.h>
#include <stdlib.h>
#include <stdint-gcc.h>
#include "nf.h"
#include "nf_types.h"
#include "../lib/uart.h"
#include "../ds/ds.h"
#include "../ut/utilities.h"

//defines
#define UART_BAUD_RATE 9600
#define NMEA_MSG_ID_SIZE 5

//NMEA message IDs from NMEA documentation
#define GGA_TYPE "GPGGA"
#define GLL_TYPE "GPGLL"
#define GSA_TYPE "GPGSA"
#define GSV_TYPE "GPGSV"
#define MSS_TYPE "GPMSS"
#define RMC_TYPE "GPRMC"
#define VTG_TYPE "GPVTG"
#define ZDA_TYPE "GPZDA"
#define OK_TO_SEND_TYPE "PSRF1"

//global
//GGA MESSAGE
char utc_time[GGA_UTC_BUFFER_SIZE];             /**< UTC Time, e.g., "161229.487" */
char latitude[GGA_LAT_BUFFER_SIZE];             /**< Latitude, e.g., "3723.2475" */
char ns_indicator[GGA_INDICATOR_SIZE];          /**< N/S Indicator, 'N' for north or 'S' for south */
char longitude[GGA_LONG_BUFFER_SIZE];            /**< Longitude, e.g., "12158.3416" */
char ew_indicator[GGA_INDICATOR_SIZE];          /**< E/W Indicator, 'E' for east or 'W' for west */
char position_fix_indicator[GGA_INDICATOR_SIZE];/**< Position Fix Indicator, see Table 1-4 */
char satellites_used[GGA_SV_USD_BUFFER_SIZE];    /**< Satellites Used, range 0 to 12 eg 07 */
char hdop[GGA_HDOP_BUFFER_SIZE];                /**< HDOP (Horizontal Dilution of Precision), e.g., "1.0" */
char msl_altitude[GGA_ALTITUDE_BUFFER_SIZE];     /**< Mean Sea Level Altitude, e.g., "1.0" */
char speed[VTG_SPEED_BUFER_SIZE];               /**< Speed, e.g., "0.0" */

float latitudeLLA_float;    /**< Latitude in degrees */
float longitudeLLA_float;   /**< Longitude in degrees */
float altitudeLLA_float;    /**< Altitude in meters */
char latitudeLLA_str[LLA_LAT_BUFFER_SIZE];      /**< Latitude in degrees */
char longitudeLLA_str[LLA_LONG_BUFFER_SIZE];    /**< Longitude in degrees */
char altitudeLLA_str[LLA_ALT_BUFFER_SIZE];      /**< Altitude in meters */

//local static
static char nmea_msg_id_buffer[NMEA_MSG_ID_SIZE];/**< Buffer to store NMEA message ID */
static char gga_msg_buffer[GGA_SIZE];            /**< Buffer to store GGA message */


//function definitions

/**
 * @brief Clear all navigation strings except UTC time.
 */
void nf_clear_nav_strings(){
	    memset(nmea_msg_id_buffer,0,sizeof(char)*NMEA_MSG_ID_SIZE); //zeroize
	    memset(gga_msg_buffer, ' ',sizeof(char)*GGA_SIZE); //zeroize msg buffer
	    memset(latitude, ' ', GGA_LAT_BUFFER_SIZE * sizeof(char));
	    memset(ns_indicator, ' ', GGA_INDICATOR_SIZE * sizeof(char));
	    memset(longitude, ' ', GGA_LONG_BUFFER_SIZE * sizeof(char));
	    memset(ew_indicator, ' ', GGA_INDICATOR_SIZE * sizeof(char));
	    memset(position_fix_indicator, ' ', GGA_INDICATOR_SIZE * sizeof(char));
	    memset(satellites_used, ' ', GGA_SV_USD_BUFFER_SIZE * sizeof(char));
	    memset(hdop, ' ', GGA_HDOP_BUFFER_SIZE * sizeof(char));
	    memset(msl_altitude, ' ', GGA_ALTITUDE_BUFFER_SIZE * sizeof(char));

	    memset(latitudeLLA_str, ' ', LLA_LAT_BUFFER_SIZE * sizeof(char));
	    memset(longitudeLLA_str, ' ', LLA_LONG_BUFFER_SIZE * sizeof(char));
	    memset(altitudeLLA_str, ' ', LLA_ALT_BUFFER_SIZE * sizeof(char));
}

/**
 * @brief Initialize the navigation fetch module.
 * This function initializes UART communication and clears navigation strings.
 * @return 0 if initialization is successful, otherwise returns 1.
 */
uint8_t nf_init(){
	cli();
	 /*
     *  Initialize UART library, pass baudrate and AVR cpu clock
     *  with the macro 
     *  UART_BAUD_SELECT() (normal speed mode )
     *  or 
     *  UART_BAUD_SELECT_DOUBLE_SPEED() ( double speed mode)
     */
    uart_init( UART_BAUD_SELECT(UART_BAUD_RATE,F_CPU) );

	// Initialize the arrays within gga_msg 
	memset(utc_time, ' ', GGA_UTC_BUFFER_SIZE * sizeof(char));
	memset(speed, ' ', VTG_SPEED_BUFER_SIZE * sizeof(char));

    nf_clear_nav_strings();


	latitudeLLA_float = 0;  
	longitudeLLA_float = 0;  
	altitudeLLA_float = 0; 
	
	
	sei(); //UART is interrupt based;	
	return NF_INIT_SUCCESS;
}

/**
 * @brief Read a single character from the serial communication.
 * This function blocks until a character is received.
 * @param outputchar Pointer to the character variable to store the read character.
 */
void get_serial_char(char* outputchar){
	unsigned int c;
	while (1){
		/*
		* Get received character from ringbuffer
		* uart_getc() returns in the lower byte the received character and 
		* in the higher byte (bitmask) the last receive error
		* UART_NO_DATA is returned when no data is available.
		*
		*/
		c = uart_getc();
		if (!( c & UART_NO_DATA ))
		{
			/*
				* new data available from UART
				* check for Frame or Overrun error
				*/
			#ifdef __DEBUG__
				if ( c & UART_FRAME_ERROR )
				{
					/* Framing Error detected, i.e no stop bit detected */
					#ifdef _DEBUG_
						char* output = "NF Frame Error! ";
						ds_print_string(output, 16, 0);
					#endif
				}
				if ( c & UART_OVERRUN_ERROR )
				{
					/* 
						* Overrun, a character already present in the UART UDR register was 
						* not read by the interrupt handler before the next character arrived,
						* one or more received characters have been dropped
						*/
					char* output = "           OR ER";
					ds_print_string(output, 16, 0);
				}
				if ( c & UART_BUFFER_OVERFLOW )
				{
					/* 
						* We are not reading the receive buffer fast enough,
						* one or more received character have been dropped 
						*/
					char* output = "OF ER";
					ds_print_string(output, 5, 0);
				}
			#endif

			/* 
			* send received character back
			*/
			*outputchar = (unsigned char)c;
			return;
		}
	}
	
}
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

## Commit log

2024-04-12 Documentation Draft 1
    Includes first schematic and proposal
2024-04-12 Software baseline
    1hz timer and timing system baseline
2024-04-13 Added switch to shematic
2024-04-13 Updated receiver interface
    Needed voltage divider on input power for NEO6-M
    Datasheet says 2.0V max. Set to 1.78V
2024-04-13 NMEA DATA READ
    NF can read NMEA data headers
    UART static lib added from Peter Fluerry
2024-04-13 fixed Rx Tx config
    [nf.c]
2024-04-13 Acq on power cycle!
2024-04-14 Document Update
    Updated Proposal Document to match current design (It may turn into the design document)
    Created 3D designs for case
    [WayFindX_BOTTOM.stl, WayFindX_TOP.stl]
2024-04-18 switch to 20x4
2024-04-19 updated top
    [WayFindX_TOP.stl]
2024-04-21 Fixed floating point errors
    LLA complete
    [main.c, nf.c]
2024-04-21 Velocity Implemented
2024-04-25 Button Baseline
    Timing/debounce needs improved
    Action button is not implemented
2024-04-25 improved button (action on press)
2024-04-25 Implemented button on release
2024-04-25 op, mem, action buttons no longer trigger in STAT_MODE
    Removed debug light
    [utilities.c, utilities.h]
2024-04-26 SD Card Foundation Work
    * Updated LCD library to use different pins
    * Updated circuit diagram Draw file
    * updated proposal file to match new diagram
2024-04-27 HW first build
    First build for integrating with perf board. Needed to rearrange some pins to make the wires flow better.
2024-04-27 Implemented button functionality minus SD card
    * removed unused code from NF
    * re-arranged nf sign calculation in conversion to LLA to not screw up integer math in negative lat/long
    *Button functionality implemented
2024-04-28 Updated print to fit bottom hardware
    [WayFindX_BOTTOM.stl]
2024-04-28 Distance calc/display imp/tested
    Implemented distance calculation.
    Tested as well... seems accurate enough taking into account floating point errors and GPS limitations of the NEO6-M
    [main.c, utilities.c, utilities.h]
2024-04-28 Initial draft of poster for modern marvels
    Created vector graphics of schematics
    Created poster initial draft and vector graphic
2024-04-30 Revert "SD card work laying foundation"
    This reverts commit 371509ca4bcdf19186b7ae860b4b19fcc1076978.
    [main.c, utilities.c]
